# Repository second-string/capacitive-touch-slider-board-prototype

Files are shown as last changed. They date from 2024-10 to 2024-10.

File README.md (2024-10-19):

# capacitive-touch-slider-board-prototype

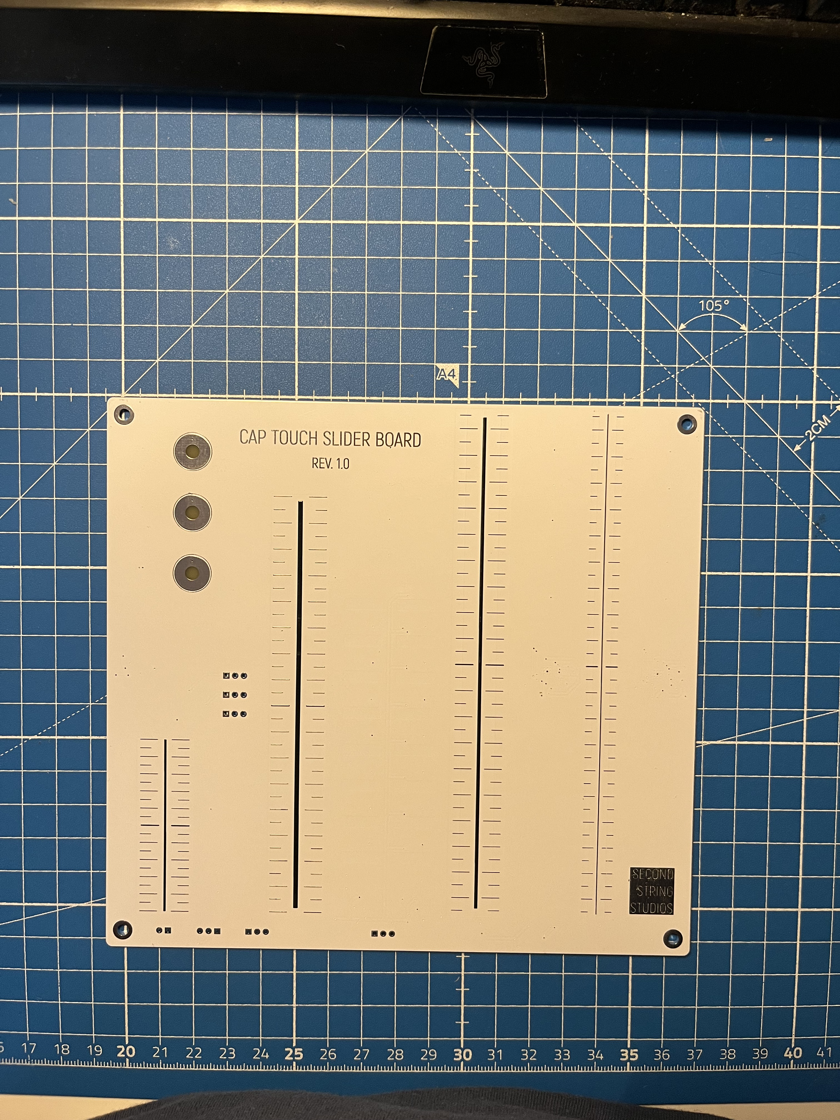
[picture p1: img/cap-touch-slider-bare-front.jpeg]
Version 1.0 of the capacitive touch slider test board front

Version 1.0 of the capacitive touch slider test board back

This repo contains a design for a prototype PCB for testing different capacitive touch slider designs. For more information on the different slider footprints, see [writeup](https://brian.team/engineering/capacitive-touch-protoype-pcbs/).

There is a schematic PDF and PCB layer prints PDF in the version 1.0 directory if you do not have KiCad. There are also Excel and interactive BOMs in the `bom/` subdirectory.

Reach out if you would like the KiCad slider schematic symbol and footprint files, they are saved in my global library and so not directly accessible from the project directory.

There is test firmware in `slider-board_rev_1_0/bringup_firmware/`. **NOTE:** This firmware is sloppy, terribly written, inefficient, and everything is hardcoded. It is only included as a reference, do not think that this will work for you out of the box.

Videos of example behavior are in the `img/` directory.

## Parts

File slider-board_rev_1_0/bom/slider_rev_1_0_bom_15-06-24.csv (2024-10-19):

Reference | Value | Footprint | Qty | DNP | Digikey | MPN | Purchase-URL
C1,C2,C4,C6,C7 | 0.1uF | Capacitor_SMD:C_0603_1608Metric | 5
C3,C5 | 4.7nF | Capacitor_SMD:C_0603_1608Metric | 2
D1,D2,D3,D4,D5,D6,D7,D8,D9,D10,D11,D12,D13,D14,D15,D16 | LED | LED_SMD:LED_SunLED_XZ_Reverse_Mount | 16
J2,J4,J5 | Conn_01x03_Pin | Connector_PinHeader_2.54mm:PinHeader_1x03_P2.54mm_Vertical | 3
J3 | Conn_01x02_Pin | Connector_PinHeader_2.54mm:PinHeader_1x02_P2.54mm_Vertical | 1
P1 | Slider_Spatial_3P_1L | Touch:Slider_SpatialInterpolation_3P_1L | 1
P2,P5,P6,P8,P9 | ~ | -- mixed values -- | 5
P7 | Slider_Resistive_3P_1L | Touch:Slider_ResistiveInterpolation_3P_1L | 1
Q1,Q2,Q3,Q4,Q5,Q6,Q7,Q8,Q9,Q10,Q11,Q12,Q13,Q14,Q15,Q16 | Q_NMOS_GSD | Package_TO_SOT_SMD:TSOT-23 | 16
R1,R17,R48 | 47k | Resistor_SMD:R_0603_1608Metric | 3
R4,R5,R6,R37,R38,R95,R96,R97 | 10k | Resistor_SMD:R_0603_1608Metric | 8
R7,R9,R14,R20,R25,R30,R33,R35,R36,R60,R61,R62,R63,R64,R65,R66,R67,R68 | 1k | Resistor_SMD:R_0603_1608Metric | 18
R8,R10,R32,R34,R39,R40,R58,R59 | 2k4 | Resistor_SMD:R_0603_1608Metric | 8
R11,R12,R13,R15,R16,R18,R19,R21,R22,R23,R24,R26,R27,R28,R29,R31,R41,R42,R43,R44,R45,R46,R47,R49,R50,R51,R52,R53,R54,R55,R56,R57 | 1k2 | Resistor_SMD:R_0603_1608Metric | 32
R69,R70,R71,R72,R73,R74,R75,R76,R77,R78,R79,R80,R81,R82,R83,R84 | 470R 1/2W | Resistor_SMD:R_0603_1608Metric | 16
R85,R86,R87,R92,R93,R94 | 2k | Resistor_SMD:R_0603_1608Metric | 6
R88,R89,R90,R91 | 1k5 | Resistor_SMD:R_0603_1608Metric | 4
TP1,TP2 | TestPoint | TestPoint:TestPoint_Pad_D3.0mm | 2
U1 | AT42QT2120 | Package_SO:TSSOP-20_4.4x6.5mm_P0.65mm | 1 |  | https://www.digikey.de/en/products/detail/microchip-technology/AT42QT2120-XUR/3678735 | AT42QT2120-XUR
U2,U3 | AT42QT2160-MMU | Package_DFN_QFN:VQFN-28-1EP_4x4mm_P0.45mm_EP2.4x2.4mm_ThermalVias | 2 |  |  | AT42QT2160-MMU | https://www.snapeda.com/api/url_track_click_mouser/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
U4,U5 | 74HCT595 | Package_DFN_QFN:DHVQFN-16-1EP_2.5x3.5mm_P0.5mm_EP1x2mm | 2

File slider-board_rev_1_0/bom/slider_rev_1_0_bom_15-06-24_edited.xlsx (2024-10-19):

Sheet: Sheet1
Reference | Value | Footprint | Qty | MPN | Digikey | LCSC
C1,C2,C4,C6,C7 | 0.1uF | Capacitor_SMD:C_0603_1608Metric | 5
C3,C5 | 4.7nF | Capacitor_SMD:C_0603_1608Metric | 2
D1,D2,D3,D4,D5,D6,D7,D8,D9,D10,D11,D12,D13,D14,D15,D16 | LED | LED_SMD:LED_SunLED_XZ_Reverse_Mount | 16 | XZMYK45WT-9 | https://www.digikey.de/en/products/detail/sunled/XZMYK45WT-9/6615715
J2,J4,J5 | Conn_01x03_Pin | Connector_PinHeader_2.54mm:PinHeader_1x03_P2.54mm_Vertical | 3
J3 | Conn_01x02_Pin | Connector_PinHeader_2.54mm:PinHeader_1x02_P2.54mm_Vertical | 1
Q1,Q2,Q3,Q4,Q5,Q6,Q7,Q8,Q9,Q10,Q11,Q12,Q13,Q14,Q15,Q16 | Q_NMOS_GSD | Package_TO_SOT_SMD:TSOT-23 | 16 | DMN3731U-7 | https://www.digikey.com/en/products/detail/diodes-incorporated/DMN3731U-7/10295271
R1,R17,R48 | 47k | Resistor_SMD:R_0603_1608Metric | 3
R4,R5,R6,R37,R38,R95,R96,R97 | 10k | Resistor_SMD:R_0603_1608Metric | 8
R7,R9,R14,R20,R25,R30,R33,R35,R36,R60,R61,R62,R63,R64,R65,R66,R67,R68 | 1k | Resistor_SMD:R_0603_1608Metric | 18
R8,R10,R32,R34,R39,R40,R58,R59 | 2k4 | Resistor_SMD:R_0603_1608Metric | 8 | RC0603FR-072K4L | https://www.digikey.de/en/products/detail/yageo/RC0603FR-072K4L/727023
R11,R12,R13,R15,R16,R18,R19,R21,R22,R23,R24,R26,R27,R28,R29,R31,R41,R42,R43,R44,R45,R46,R47,R49,R50,R51,R52,R53,R54,R55,R56,R57 | 1k2 | Resistor_SMD:R_0603_1608Metric | 32 | RMCF0603FT1K20 | https://www.digikey.de/en/products/detail/stackpole-electronics-inc/RMCF0603FT1K20/1761134
R69,R70,R71,R72,R73,R74,R75,R76,R77,R78,R79,R80,R81,R82,R83,R84 | 470R 1/2W | Resistor_SMD:R_0603_1608Metric | 16 | RCS0603470RJNEA | https://www.digikey.de/en/products/detail/vishay-dale/RCS0603470RJNEA/5866959
R85,R86,R87,R92,R93,R94 | 2k | Resistor_SMD:R_0603_1608Metric | 6 | RMCF0603FT2K00 | https://www.digikey.de/en/products/detail/stackpole-electronics-inc/RMCF0603FT2K00/1761334
R88,R89,R90,R91 | 1k5 | Resistor_SMD:R_0603_1608Metric | 4 | RMCF0603FT1K50 | https://www.digikey.de/en/products/detail/stackpole-electronics-inc/RMCF0603FT1K50/1761186
U1 | AT42QT2120 | Package_SO:TSSOP-20_4.4x6.5mm_P0.65mm | 1 | AT42QT2120-XUR | https://www.digikey.de/en/products/detail/microchip-technology/AT42QT2120-XUR/3678735
U2,U3 | AT42QT2160-MMU | Package_DFN_QFN:VQFN-28-1EP_4x4mm_P0.45mm_EP2.4x2.4mm_ThermalVias | 2 | AT42QT2160-MMU | https://www.digikey.de/en/products/detail/microchip-technology/AT42QT2160-MMUR/7354599
U4,U5 | 74HCT595 | Package_DFN_QFN:DHVQFN-16-1EP_2.5x3.5mm_P0.5mm_EP1x2mm | 2 | 74HCT595BQ,115 | https://www.digikey.de/en/products/detail/nexperia-usa-inc/74HCT595BQ-115/1023167

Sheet: Sheet2
XZMYK45WT-9 | 16
DMN3731U-7 | 16
RC0603FR-072K4L | 8
RMCF0603FT1K20 | 32
RCS0603470RJNEA | 16
RMCF0603FT2K00 | 6
RMCF0603FT1K50 | 4
AT42QT2120-XUR | 1
AT42QT2160-MMU | 2
74HCT595BQ,115 | 2

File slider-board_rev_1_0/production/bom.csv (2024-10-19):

Designator | Footprint | Quantity | Value | LCSC Part #
C1, C2, C4, C6, C7 | 0603 | 5 | 0.1uF
C3, C5 | 0603 | 2 | 4.7nF
D1, D10, D11, D12, D13, D14, D15, D16, D2, D3, D4, D5, D6, D7, D8, D9 | LED_SunLED_XZ_Reverse_Mount | 16 | LED
J2, J4, J5 | PinHeader_1x03_P2.54mm_Vertical | 3 | Conn_01x03_Pin
J3 | PinHeader_1x02_P2.54mm_Vertical | 1 | Conn_01x02_Pin
P1 | Slider_SpatialInterpolation_3P_1L | 1 | Slider_Spatial_3P_1L
P2, P5, P6 | Cap_Touch_Ring_Small | 3 | ~
P7 | Slider_ResistiveInterpolation_3P_1L | 1 | Slider_Resistive_3P_1L
P8 | Slider_ResistiveInterpolation_7P_2L | 1 | ~
P9 | Slider_ResistiveInterpolation_Thin_7P_2L | 1 | ~
Q1, Q10, Q11, Q12, Q13, Q14, Q15, Q16, Q2, Q3, Q4, Q5, Q6, Q7, Q8, Q9 | TSOT-23 | 16 | Q_NMOS_GSD
R1, R17, R48 | 0603 | 3 | 47k
R10, R32, R34, R39, R40, R58, R59, R8 | 0603 | 8 | 2k4
R11, R12, R13, R15, R16, R18, R19, R21, R22, R23, R24, R26, R27, R28, R29, R31, R41, R42, R43, R44, R45, R46, R47, R49, R50, R51, R52, R53, R54, R55, R56, R57 | 0603 | 32 | 1k2
R14, R20, R25, R30, R33, R35, R36, R60, R61, R62, R63, R64, R65, R66, R67, R68, R7, R9 | 0603 | 18 | 1k
R37, R38, R4, R5, R6, R95, R96, R97 | 0603 | 8 | 10k
R69, R70, R71, R72, R73, R74, R75, R76, R77, R78, R79, R80, R81, R82, R83, R84 | 0603 | 16 | 470R 1/2W
R85, R86, R87, R92, R93, R94 | 0603 | 6 | 2k
R88, R89, R90, R91 | 0603 | 4 | 1k5
TP1, TP2 | TestPoint_Pad_D3.0mm | 2 | TestPoint
U1 | TSSOP-20_4.4x6.5mm_P0.65mm | 1 | AT42QT2120 | AT42QT2120-XUR
U2, U3 | VQFN-28-1EP_4x4mm_P0.45mm_EP2.4x2.4mm_ThermalVias | 2 | AT42QT2160-MMU | AT42QT2160-MMU
U4, U5 | DHVQFN-16-1EP_2.5x3.5mm_P0.5mm_EP1x2mm | 2 | 74HCT595

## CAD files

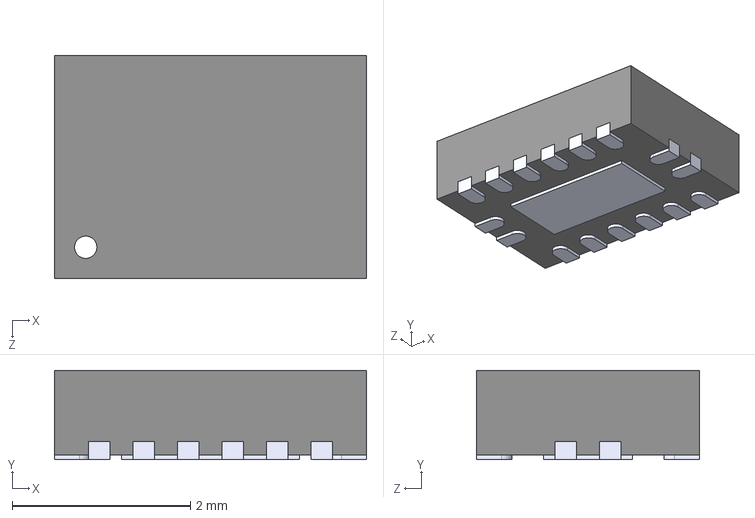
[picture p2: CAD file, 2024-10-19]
slider-board_rev_1_0/symbols_and_footprints/74HCT595BQ/74HCT595BQ-Q100,11.STEP
3.50 x 1.00 x 2.50 mm

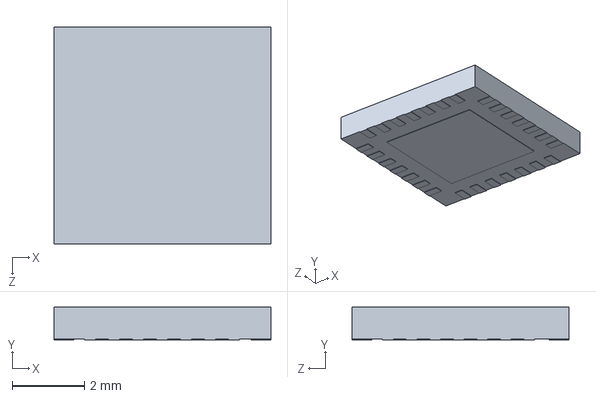
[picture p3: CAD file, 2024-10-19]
slider-board_rev_1_0/symbols_and_footprints/AT42QT2160-MMU/AT42QT2160-MMU.step
6.00 x 0.9 x 6.00 mm

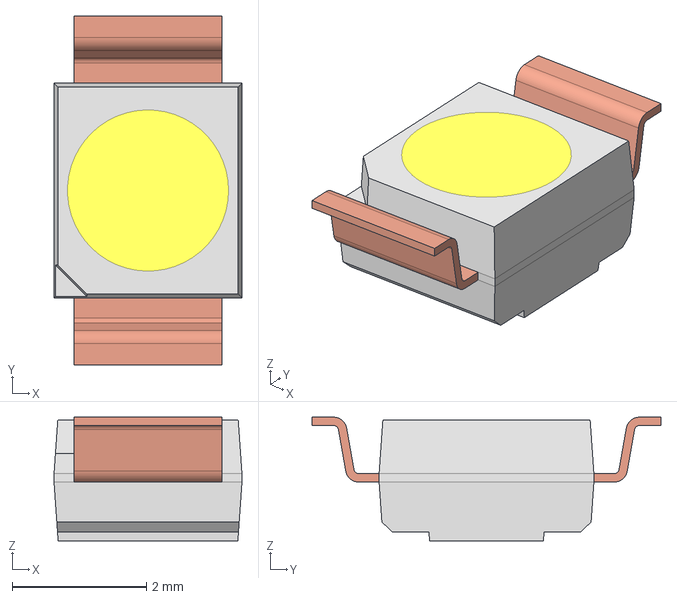
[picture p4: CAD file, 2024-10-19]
slider-board_rev_1_0/symbols_and_footprints/XZxx45S/80472LED_SMD_PLCC-2_reverse_gullwing.stp
2.80 x 5.20 x 1.84 mm

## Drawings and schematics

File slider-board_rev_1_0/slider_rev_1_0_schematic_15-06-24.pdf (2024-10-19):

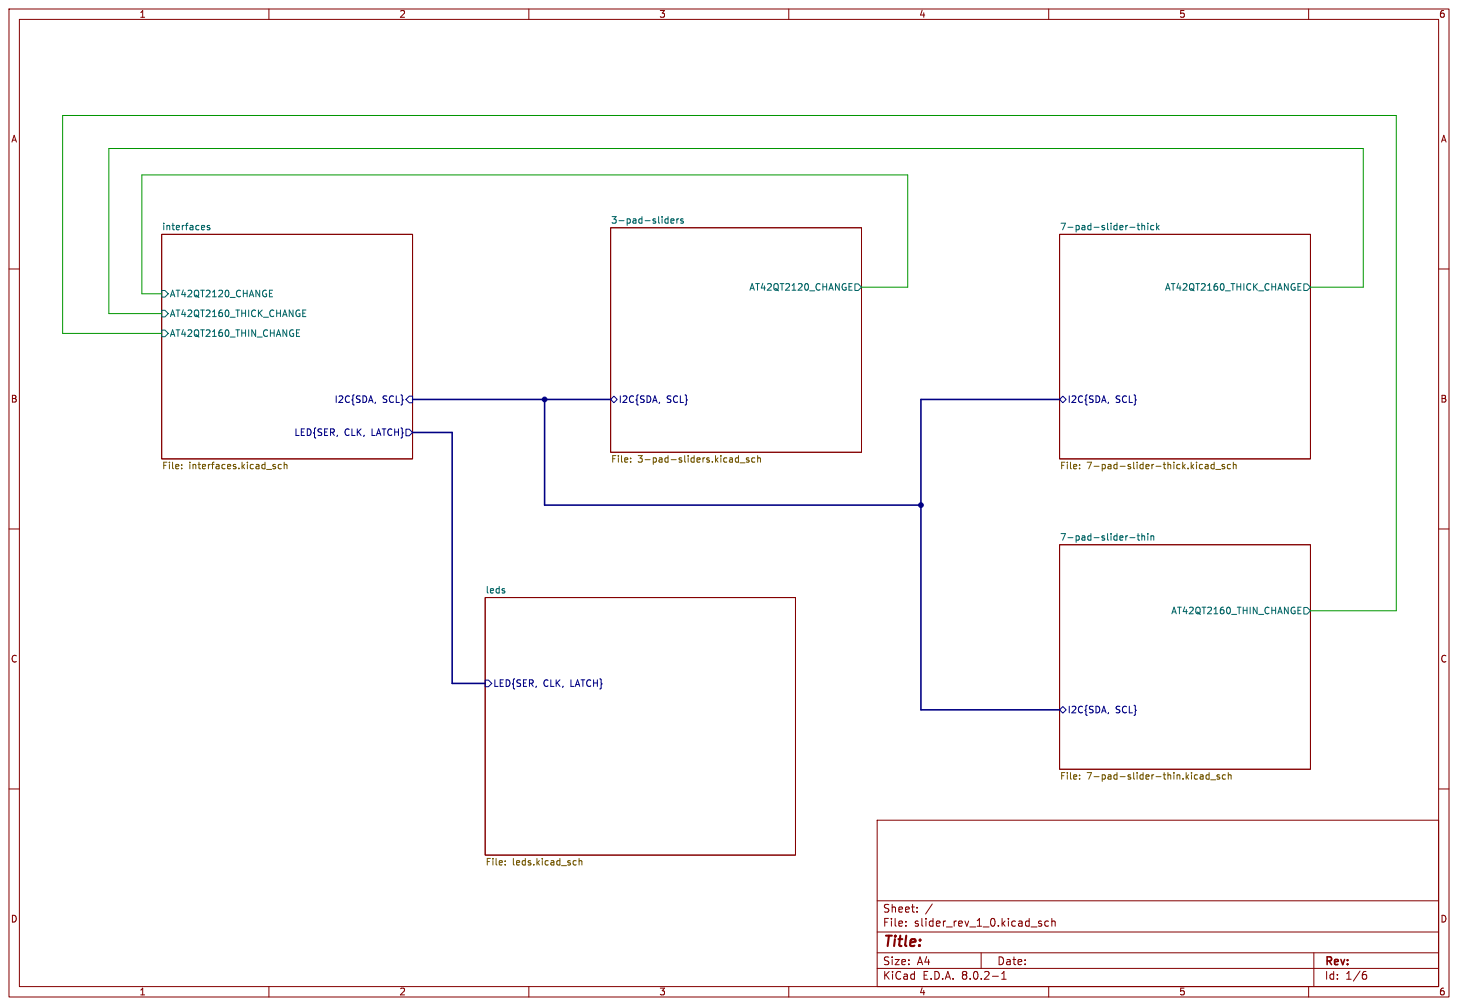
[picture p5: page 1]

3-pad-sliders File: 3-pad-sliders.kicad_sch

7-pad-slider-thick File: 7-pad-slider-thick.kicad_sch

LED{SER, CLK, LATCH}
leds File: leds.kicad_sch

7-pad-slider-thin File: 7-pad-slider-thin.kicad_sch

Id: 1/6 Title: File: slider_rev_1_0.kicad_sch Sheet: /

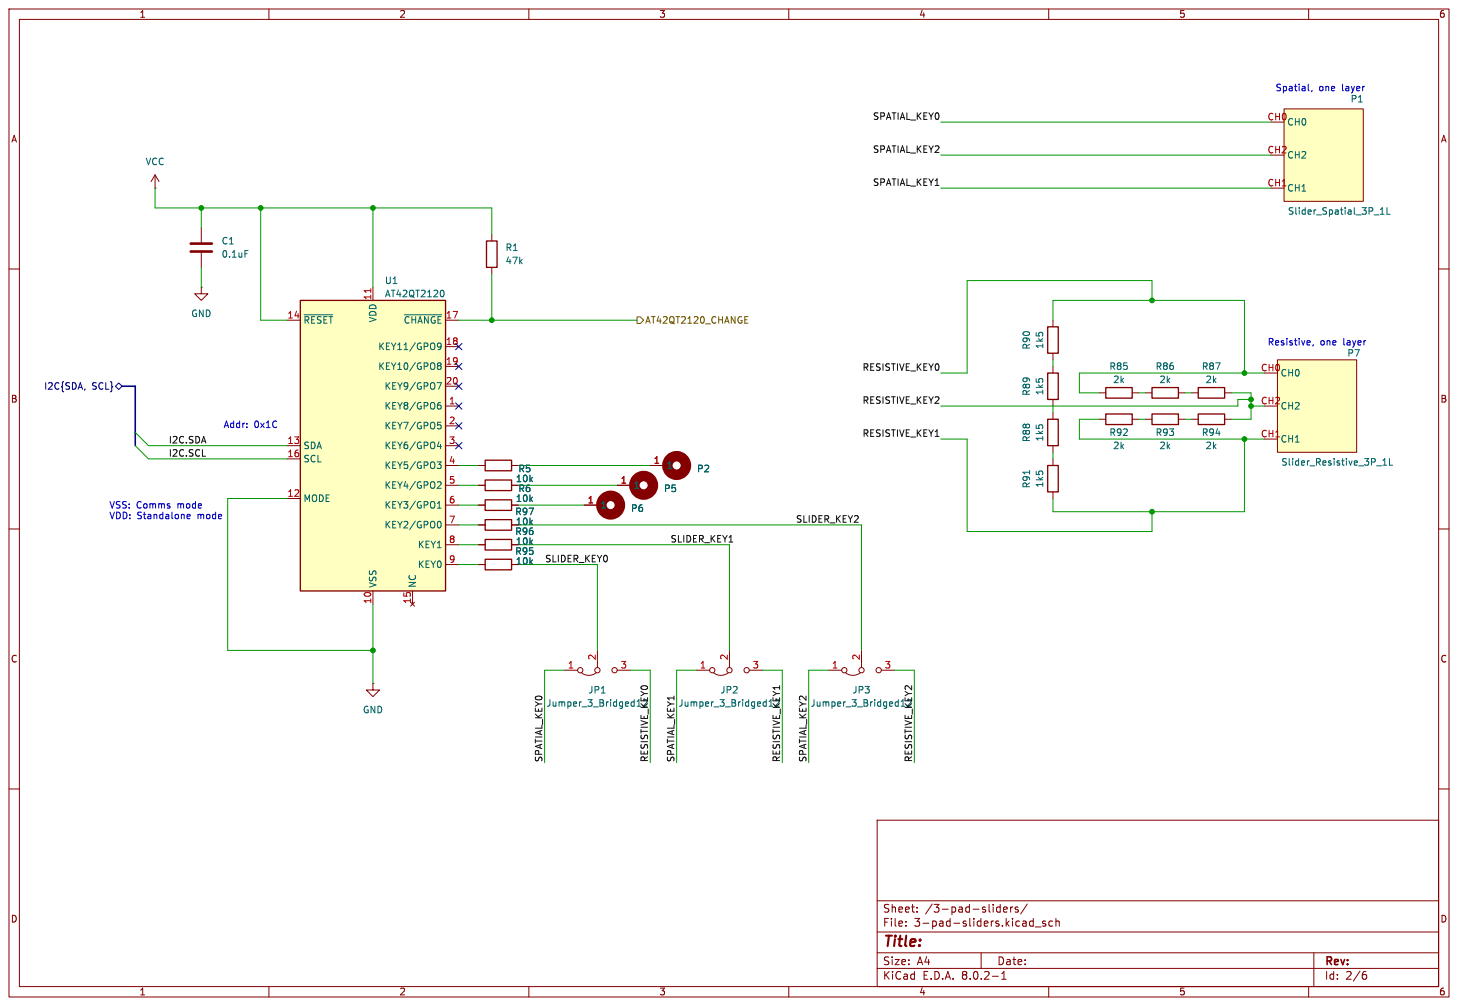
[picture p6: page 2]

Id: 2/6 Title: File: 3-pad-sliders.kicad_sch Sheet: /3-pad-sliders/

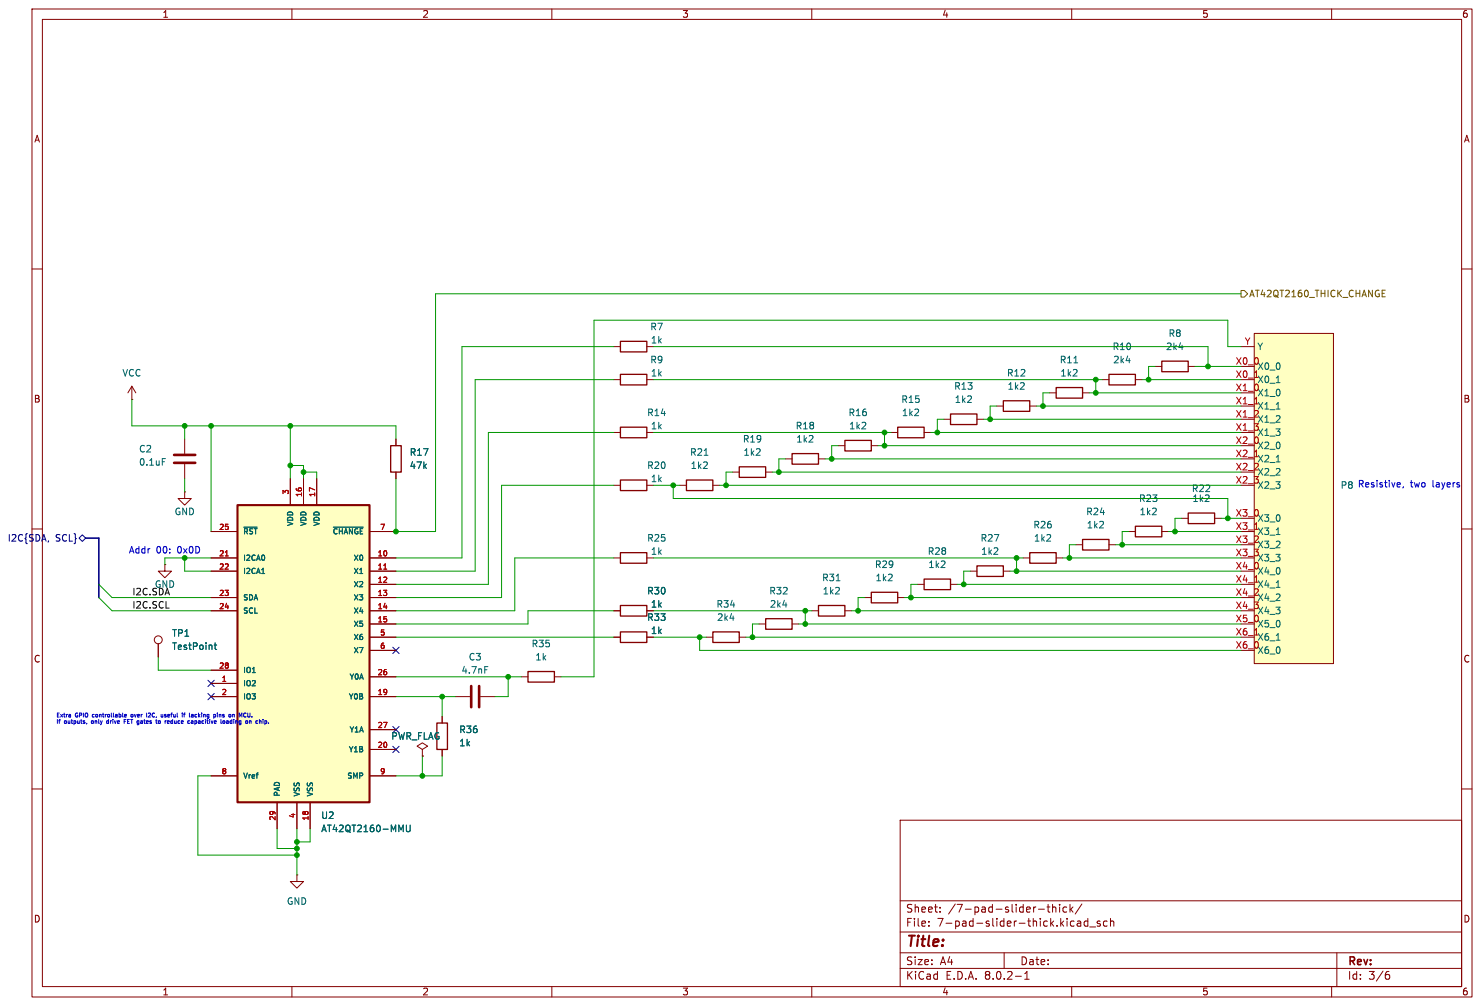
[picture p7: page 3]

4 X6 5 X7 6 ~{CHANGE} 7 Vref 8 SMP 9 U2AT42QT2160-MMU GND

Id: 3/6 Title: File: 7-pad-slider-thick.kicad_sch Sheet: /7-pad-slider-thick/

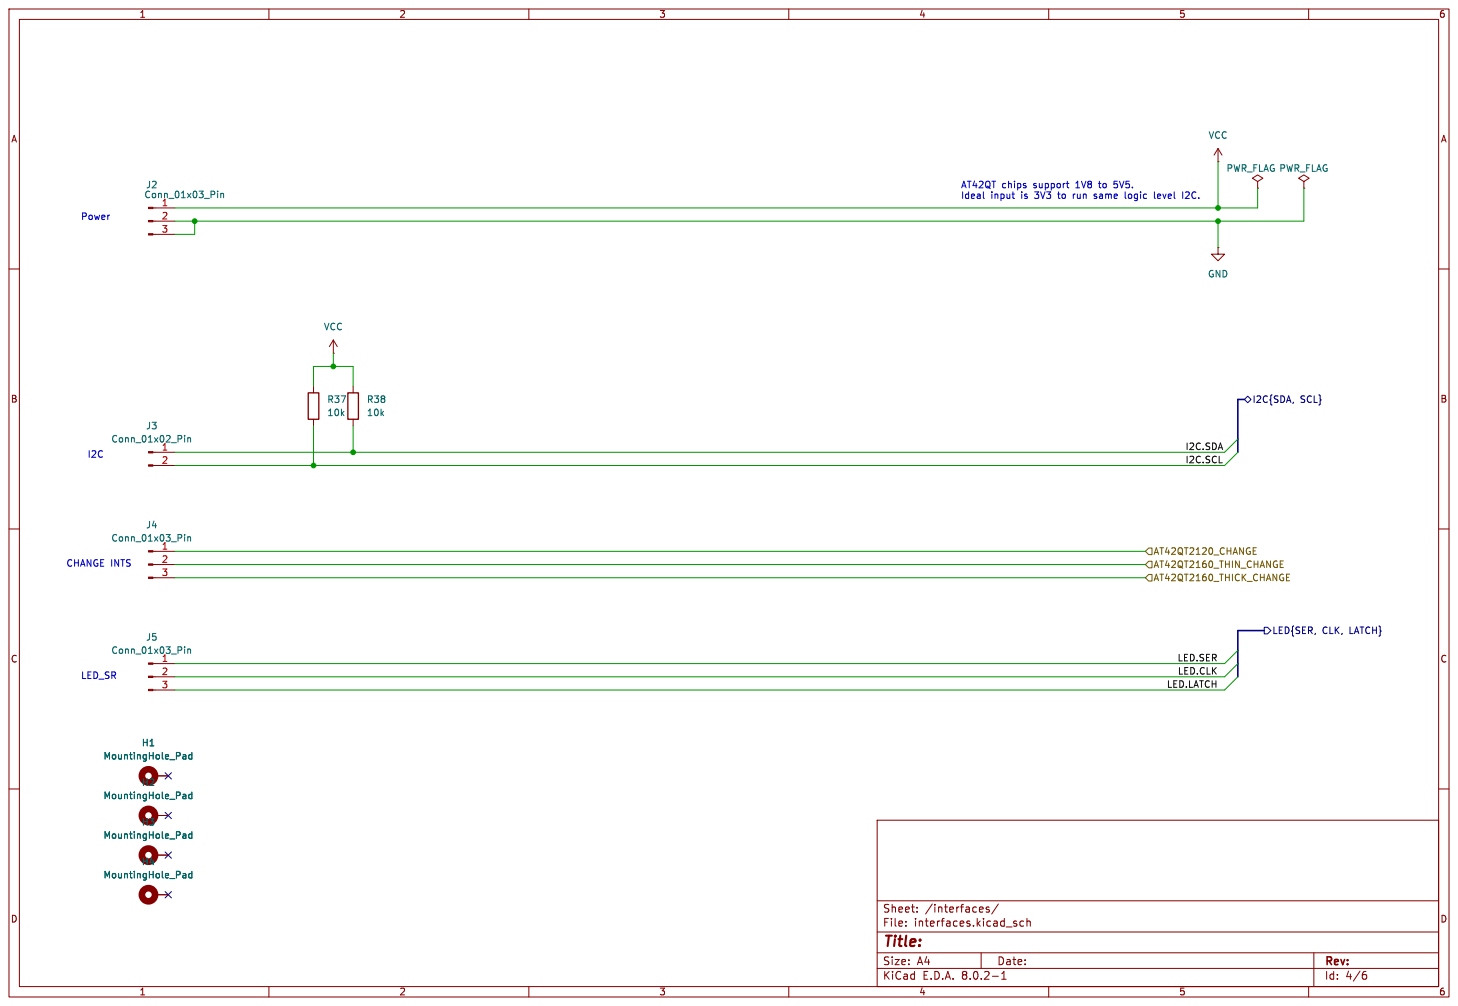
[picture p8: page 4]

Ideal input is 3V3 to run same logic level I2C. H1 MountingHole_Pad H4 MountingHole_Pad H2 MountingHole_Pad H3 MountingHole_Pad

LED{SER, CLK, LATCH}

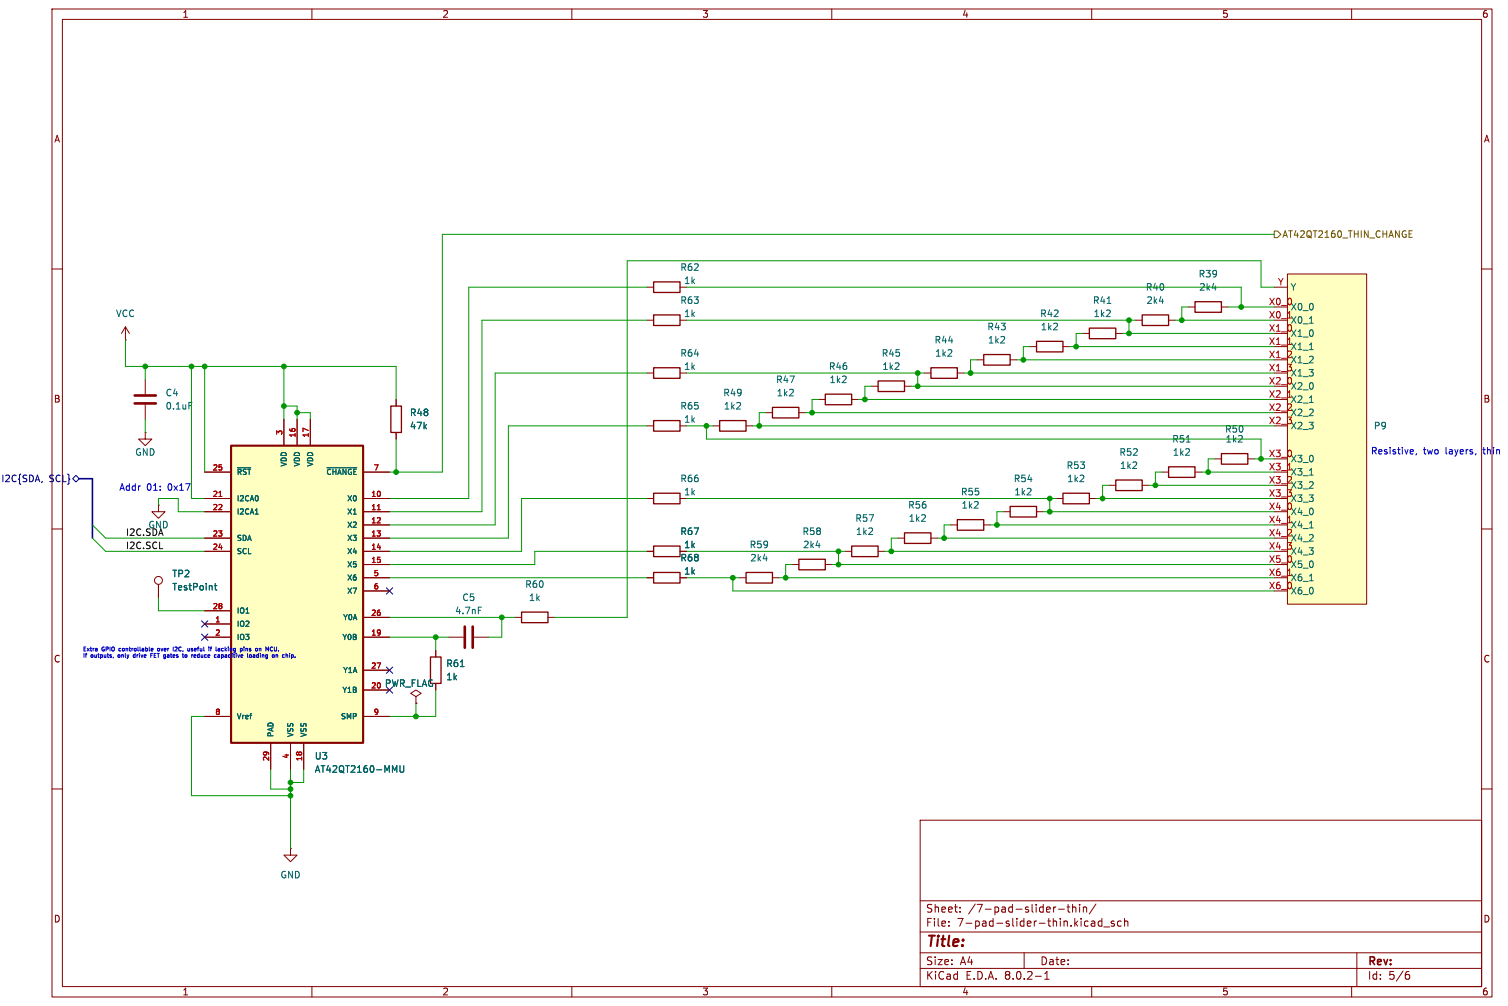
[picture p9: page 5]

4 X6 5 X7 6 ~{CHANGE} 7 Vref 8 SMP 9 TP2 TestPoint R48

4 X6 5 X7 6 ~{CHANGE} 7 Vref 8 SMP 9 U3AT42QT2160-MMU

Id: 5/6 Title: File: 7-pad-slider-thin.kicad_sch Sheet: /7-pad-slider-thin/

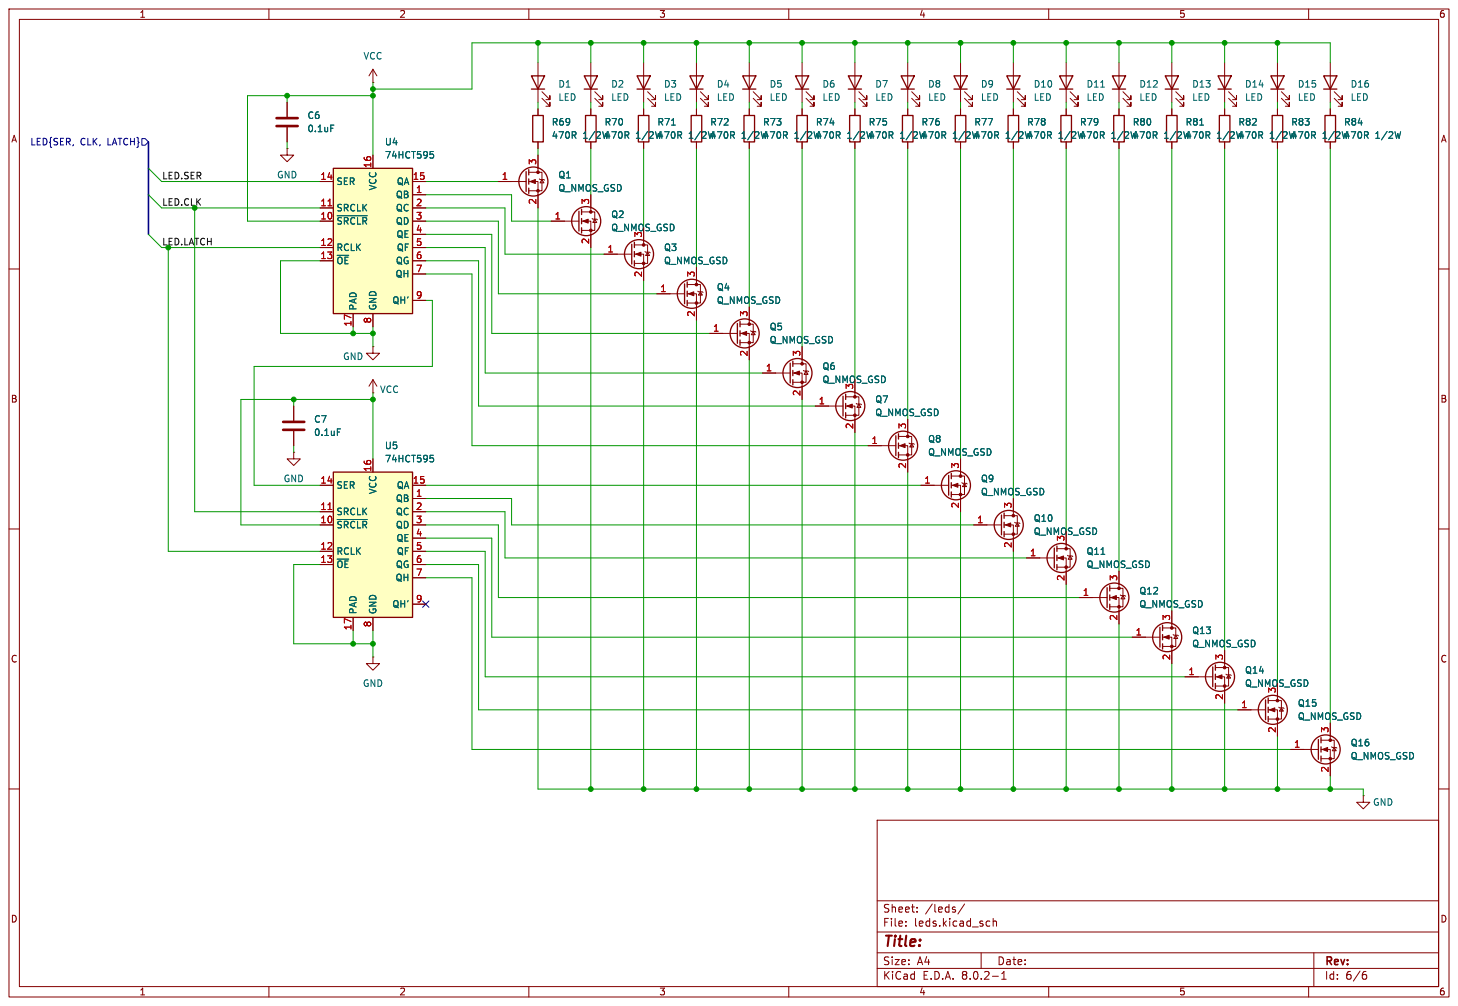
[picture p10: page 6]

Id: 6/6 Title: File: leds.kicad_sch Sheet: /leds/

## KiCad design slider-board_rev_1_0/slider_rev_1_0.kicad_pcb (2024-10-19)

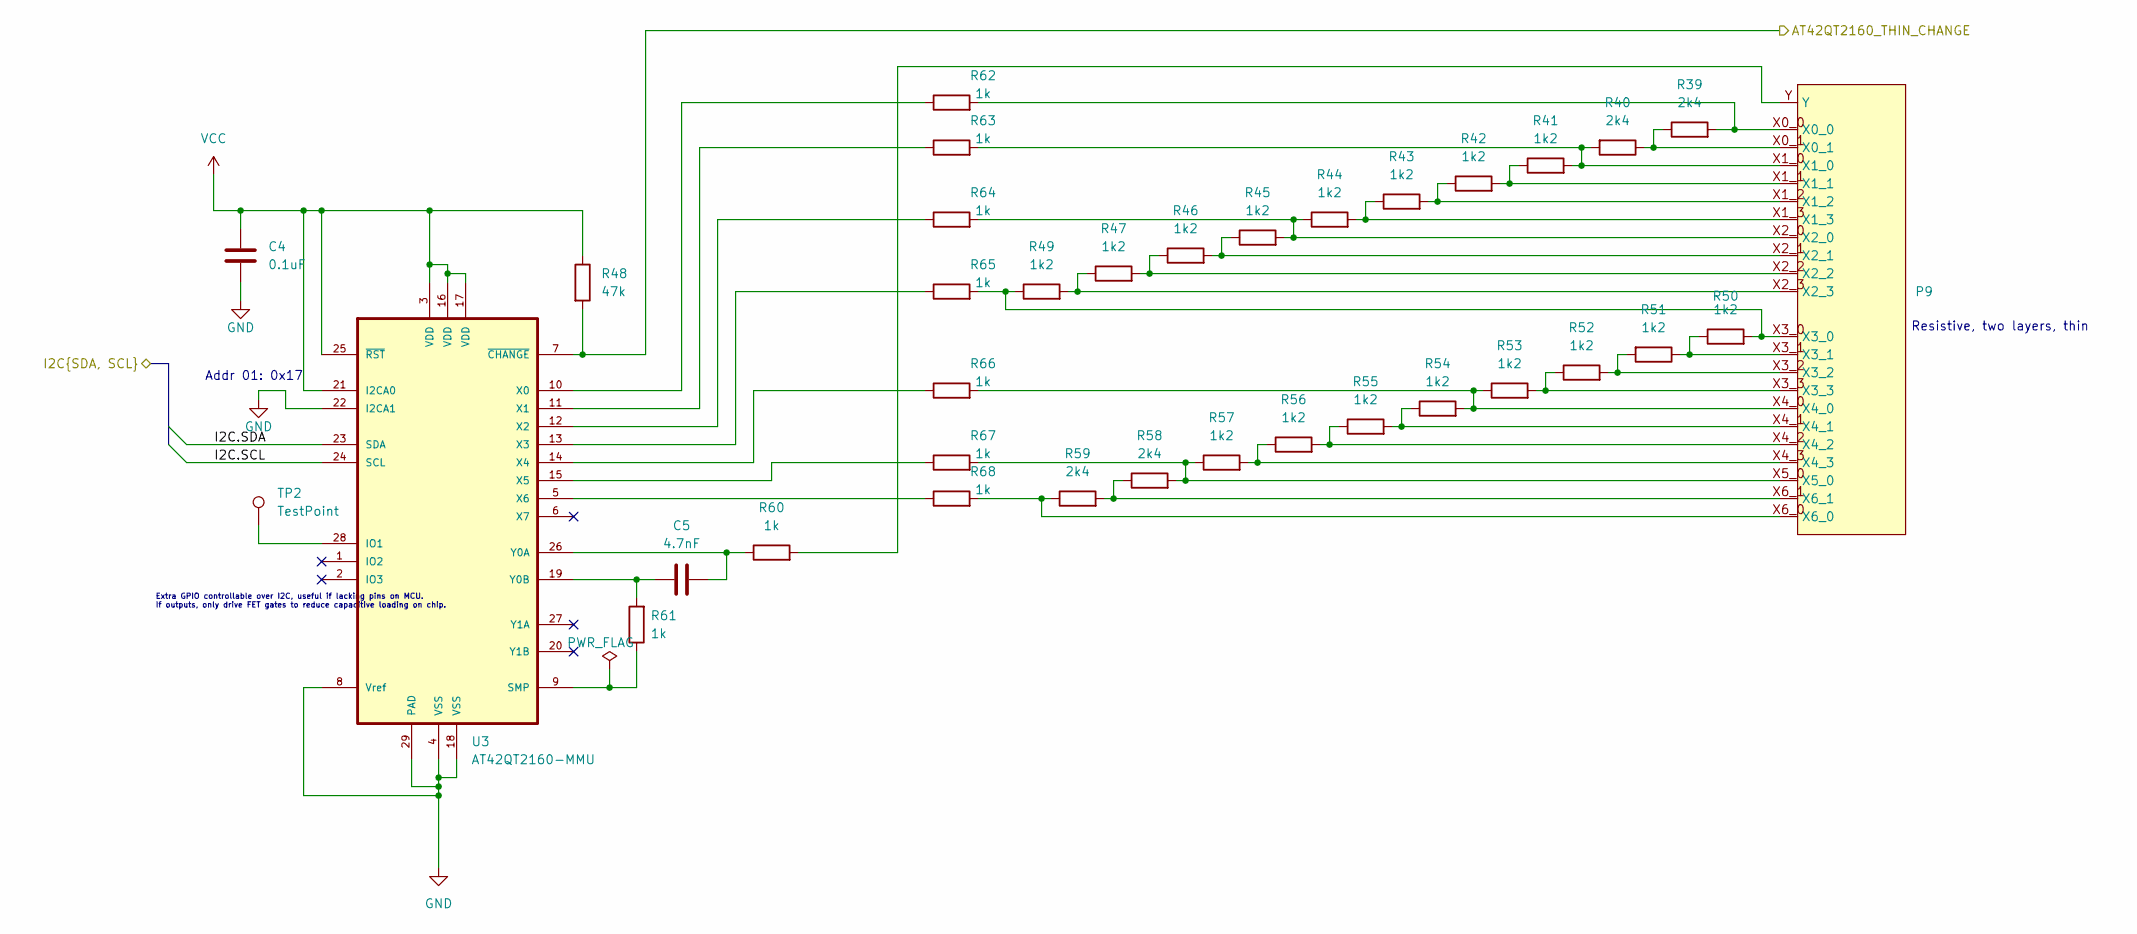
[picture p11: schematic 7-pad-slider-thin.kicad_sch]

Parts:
C4: 0.1uF; C_0603_1608Metric
C5: 4.7nF; C_0603_1608Metric
P9: Slider_ResistiveInterpolation_Thin_7P_2L
R39, R40, R58, R59: 2k4; R_0603_1608Metric
R41, R42, R43, R44, R45, R46, R47, R49, R50, R51, R52, R53, R54, R55, R56, R57: 1k2; R_0603_1608Metric
R48: 47k; R_0603_1608Metric
R60, R61, R62, R63, R64, R65, R66, R67, R68: 1k; R_0603_1608Metric
TP2: TestPoint; TestPoint_Pad_D3.0mm
U3: AT42QT2160-MMU; VQFN-28-1EP_4x4mm_P0.45mm_EP2.4x2.4mm_ThermalVias; MPN AT42QT2160-MMU

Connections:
/3-pad-sliders/I2C.SCL: U3.24 (SCL); also elsewhere on the board
/3-pad-sliders/I2C.SDA: U3.23 (SDA); also elsewhere on the board
/7-pad-slider-thin/AT42QT2160_THIN_CHANGE: R48.2, U3.7 (~CHANGE); also elsewhere on the board
GND: C4.2, U3.4 (VSS), U3.8 (Vref), U3.18 (VSS), U3.22 (I2CA1), U3.29 (PAD); also elsewhere on the board
unnamed: P9.X0_0, R39.2, R62.2
unnamed: P9.X0_1, R39.1, R40.1
unnamed: P9.X1_0, R40.2, R41.2, R63.2
unnamed: P9.X1_1, R41.1, R42.2
unnamed: P9.X1_2, R42.1, R43.2
unnamed: P9.X1_3, R43.1, R44.2
unnamed: P9.X2_0, R44.1, R45.2, R64.2
unnamed: P9.X2_1, R45.1, R46.2
unnamed: P9.X2_2, R46.1, R47.2
unnamed: P9.X2_3, R47.1, R49.2
unnamed: P9.X3_0, R49.1, R50.2, R65.2
unnamed: P9.X3_1, R50.1, R51.1
unnamed: P9.X3_2, R51.2, R52.2
unnamed: P9.X3_3, R52.1, R53.2
unnamed: P9.X4_0, R53.1, R54.2, R66.2
unnamed: P9.X4_1, R54.1, R55.2
unnamed: P9.X4_2, R55.1, R56.2
unnamed: P9.X4_3, R56.1, R57.2
unnamed: P9.X5_0, R57.1, R58.2, R67.2
unnamed: P9.X6_0, R59.1, R68.2
unnamed: P9.X6_1, R58.1, R59.2
unnamed: P9.Y, R60.2
unnamed: TP2.1, U3.28 (IO1)
unnamed: R61.1, U3.9 (SMP)
unnamed: R62.1, U3.10 (X0)
unnamed: R63.1, U3.11 (X1)
unnamed: R64.1, U3.12 (X2)
unnamed: R65.1, U3.13 (X3)
unnamed: R66.1, U3.14 (X4)
unnamed: R67.1, U3.15 (X5)
unnamed: R68.1, U3.5 (X6)
unnamed: C5.2, R60.1, U3.26 (Y0A)
unnamed: C5.1, R61.2, U3.19 (Y0B)
VCC: C4.1, R48.1, U3.3 (VDD), U3.16 (VDD), U3.17 (VDD), U3.21 (I2CA0), U3.25 (~RST); also elsewhere on the board

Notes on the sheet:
Resistive, two layers, thin
Extra GPIO controllable over I2C, useful if lacking pins on MCU. If outputs, only drive FET gates to reduce capacitive loading on chip.
Addr 01: 0x17

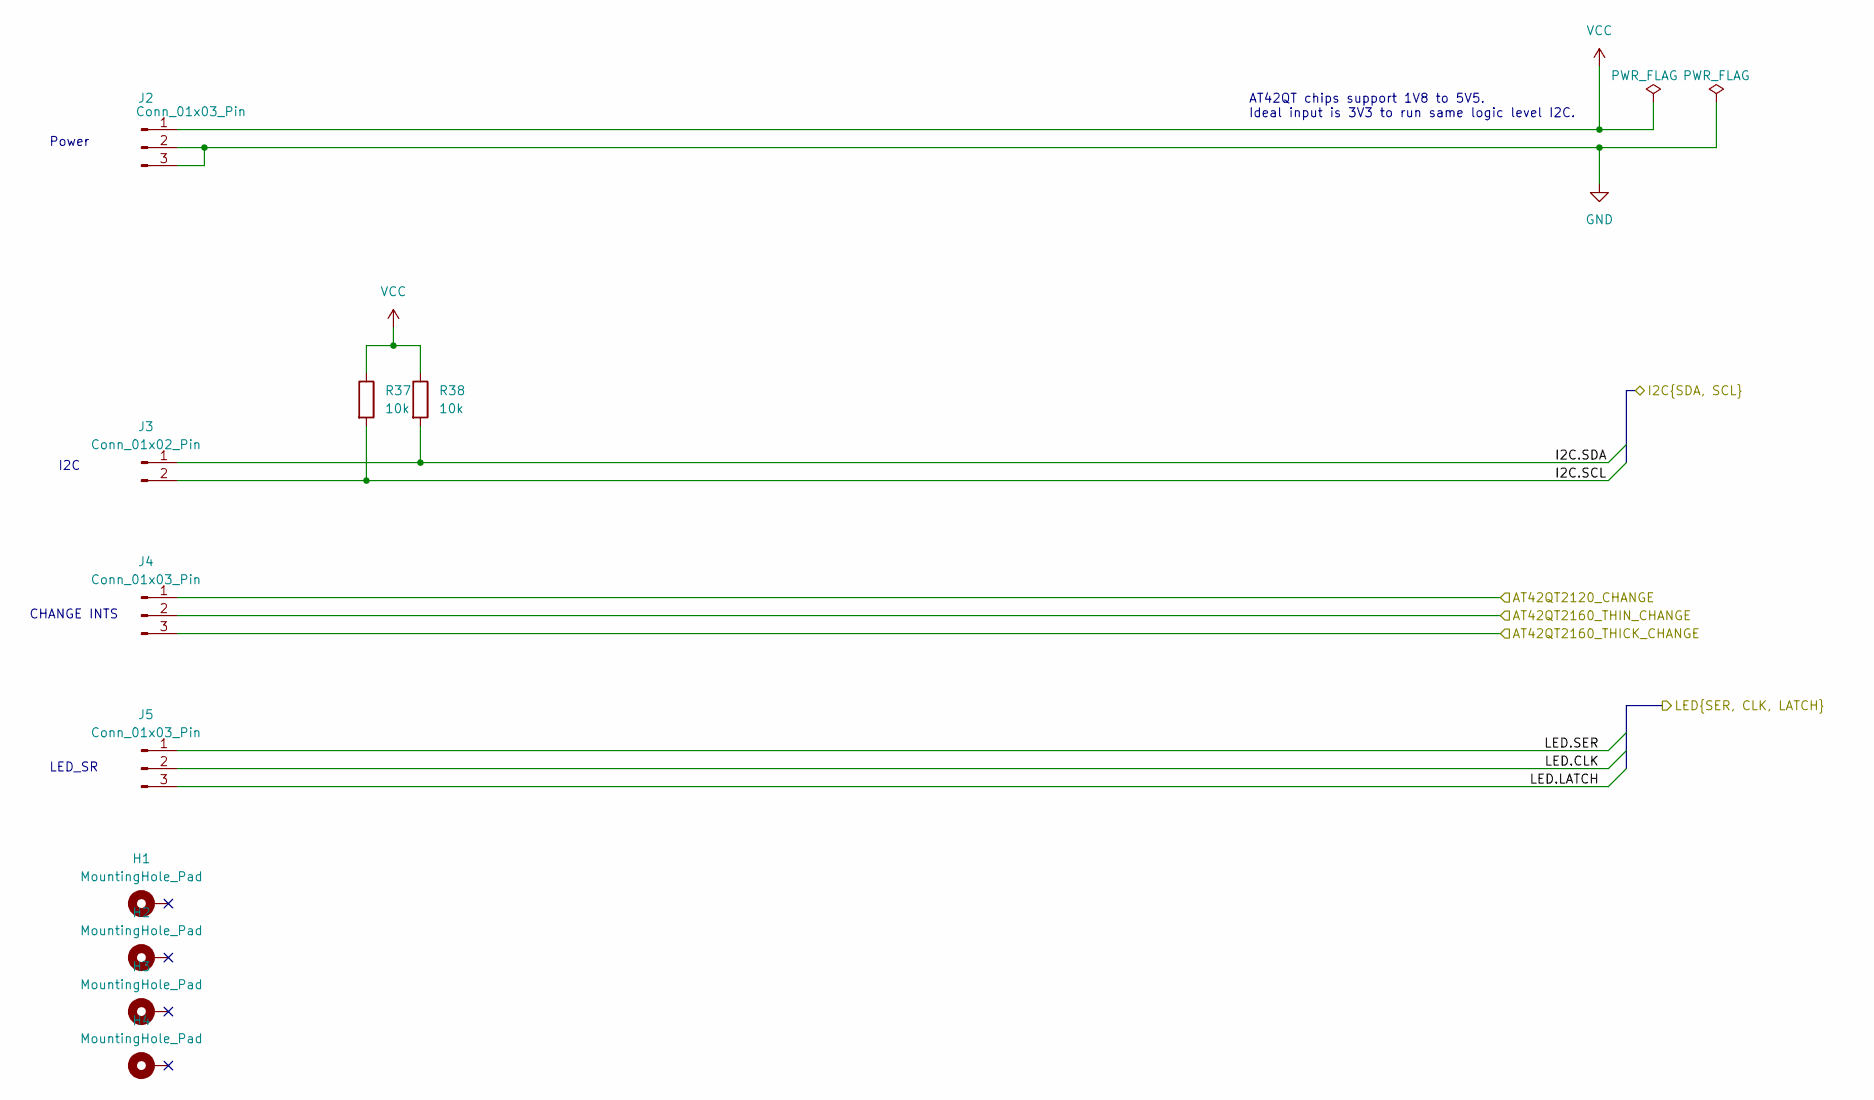
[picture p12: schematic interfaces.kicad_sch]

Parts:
H1, H2, H3, H4: MountingHole_Pad; MountingHole_3.2mm_M3_DIN965_Pad
J2, J4, J5: Conn_01x03_Pin; PinHeader_1x03_P2.54mm_Vertical
J3: Conn_01x02_Pin; PinHeader_1x02_P2.54mm_Vertical
R37, R38: 10k; R_0603_1608Metric

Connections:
/3-pad-sliders/AT42QT2120_CHANGE: J4.1; also elsewhere on the board
/3-pad-sliders/I2C.SCL: J3.2, R37.2; also elsewhere on the board
/3-pad-sliders/I2C.SDA: J3.1, R38.2; also elsewhere on the board
/7-pad-slider-thick/AT42QT2160_THICK_CHANGE: J4.3; also elsewhere on the board
/7-pad-slider-thin/AT42QT2160_THIN_CHANGE: J4.2; also elsewhere on the board
/interfaces/LED.CLK: J5.2; also elsewhere on the board
/interfaces/LED.LATCH: J5.3; also elsewhere on the board
/interfaces/LED.SER: J5.1; also elsewhere on the board
GND: J2.2, J2.3; also elsewhere on the board
VCC: J2.1, R37.1, R38.1; also elsewhere on the board

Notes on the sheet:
LED_SR
CHANGE INTS
AT42QT chips support 1V8 to 5V5. Ideal input is 3V3 to run same logic level I2C.
Power
I2C

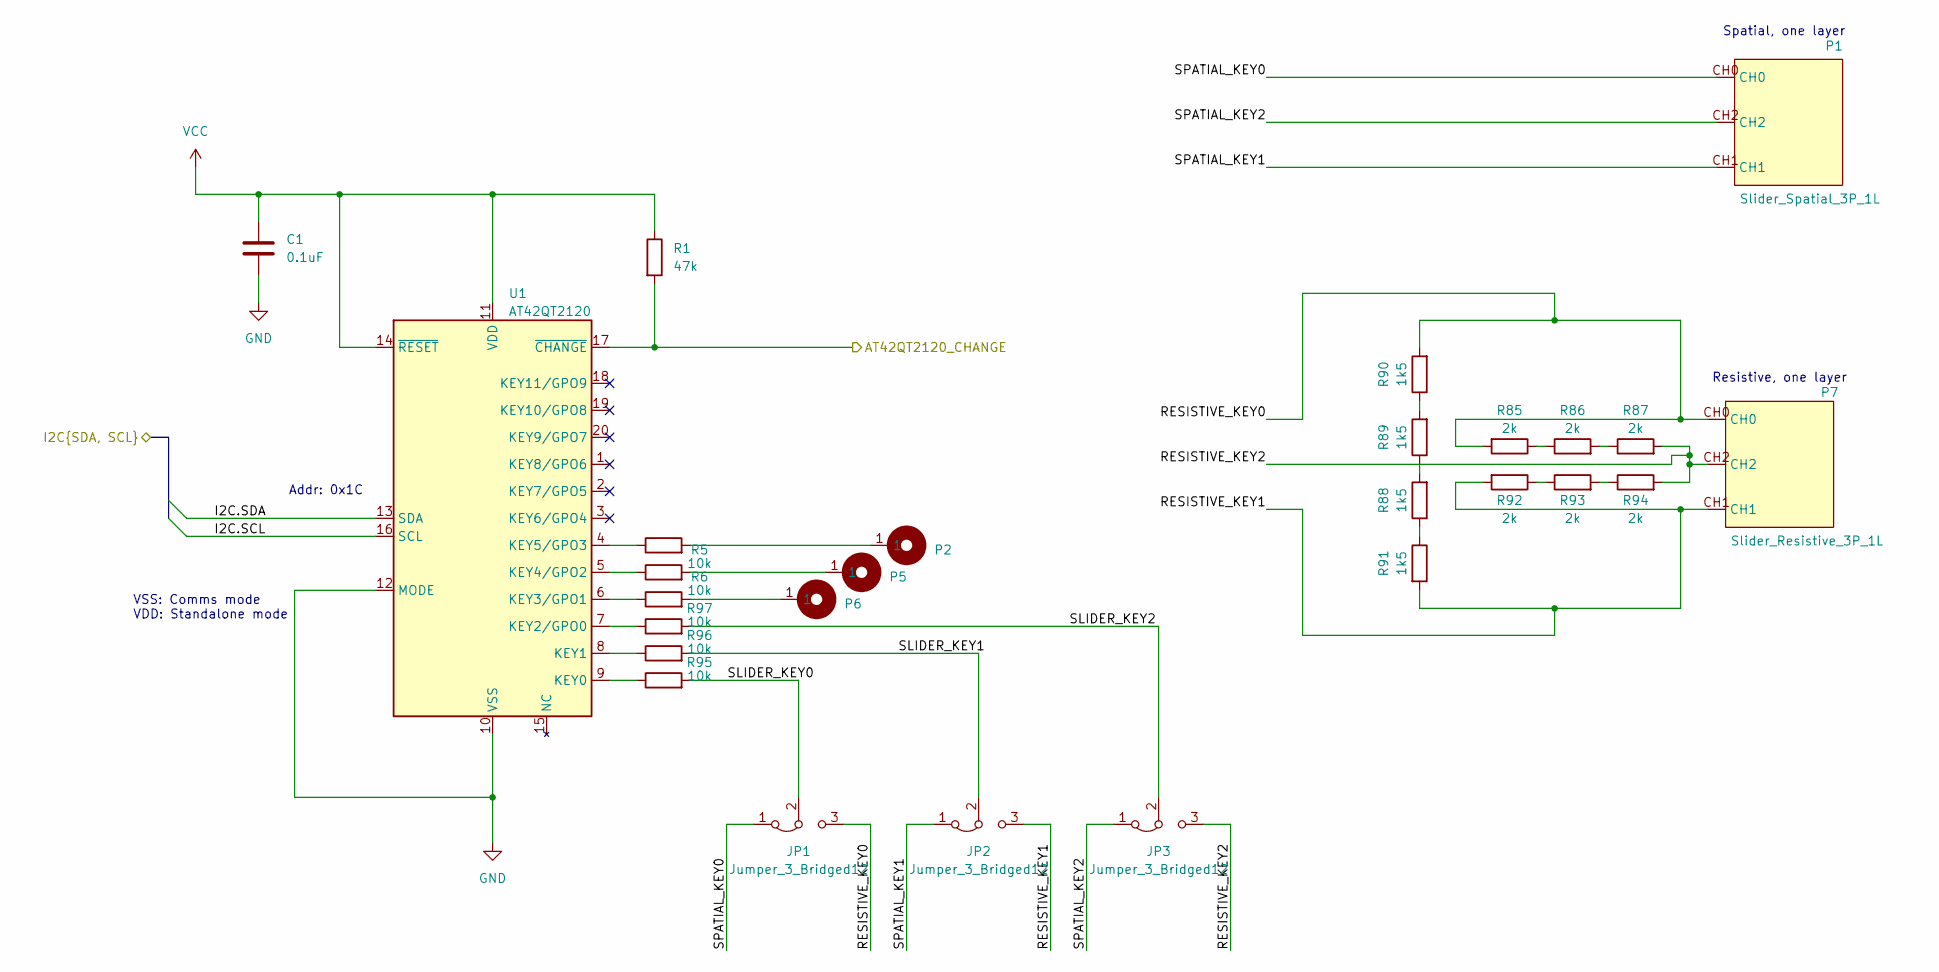
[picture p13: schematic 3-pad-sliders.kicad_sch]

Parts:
C1: 0.1uF; C_0603_1608Metric
JP1, JP2, JP3: Jumper_3_Bridged12; PinHeader_1x03_P2.54mm_Vertical
P1: Slider_Spatial_3P_1L; Slider_SpatialInterpolation_3P_1L
P2, P5, P6: Cap_Touch_Ring_Small
P7: Slider_Resistive_3P_1L; Slider_ResistiveInterpolation_3P_1L
R1: 47k; R_0603_1608Metric
R4, R5, R6, R95, R96, R97: 10k; R_0603_1608Metric
R85, R86, R87, R92, R93, R94: 2k; R_0603_1608Metric
R88, R89, R90, R91: 1k5; R_0603_1608Metric
U1: AT42QT2120; TSSOP-20_4.4x6.5mm_P0.65mm; MPN AT42QT2120-XUR

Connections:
/3-pad-sliders/AT42QT2120_CHANGE: R1.2, U1.17 (~CHANGE); also elsewhere on the board
/3-pad-sliders/I2C.SCL: U1.16 (SCL); also elsewhere on the board
/3-pad-sliders/I2C.SDA: U1.13 (SDA); also elsewhere on the board
/3-pad-sliders/RESISTIVE_KEY0: JP1.3 (B), P7.CH0, R85.2, R90.2
/3-pad-sliders/RESISTIVE_KEY1: JP2.3 (B), P7.CH1, R91.2, R92.2
/3-pad-sliders/RESISTIVE_KEY2: JP3.3 (B), P7.CH2, R87.2, R94.2
/3-pad-sliders/SLIDER_KEY0: JP1.2 (C), R95.2
/3-pad-sliders/SLIDER_KEY1: JP2.2 (C), R96.2
/3-pad-sliders/SLIDER_KEY2: JP3.2 (C), R97.2
/3-pad-sliders/SPATIAL_KEY0: JP1.1 (A), P1.CH0
/3-pad-sliders/SPATIAL_KEY1: JP2.1 (A), P1.CH1
/3-pad-sliders/SPATIAL_KEY2: JP3.1 (A), P1.CH2
GND: C1.2, U1.10 (VSS), U1.12 (MODE); also elsewhere on the board
unnamed: P2.1, R4.2
unnamed: P5.1, R5.2
unnamed: P6.1, R6.2
unnamed: R85.1, R86.1
unnamed: R86.2, R87.1
unnamed: R88.1, R91.1
unnamed: R88.2, R89.1
unnamed: R89.2, R90.1
unnamed: R92.1, R93.1
unnamed: R93.2, R94.1
unnamed: R95.1, U1.9 (KEY0)
unnamed: R96.1, U1.8 (KEY1)
unnamed: R97.1, U1.7 (KEY2/GPO0)
unnamed: R6.1, U1.6 (KEY3/GPO1)
unnamed: R5.1, U1.5 (KEY4/GPO2)
unnamed: R4.1, U1.4 (KEY5/GPO3)
VCC: C1.1, R1.1, U1.11 (VDD), U1.14 (~RESET); also elsewhere on the board

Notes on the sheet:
Resistive, one layer
VSS: Comms mode VDD: Standalone mode
Spatial, one layer
Addr: 0x1C

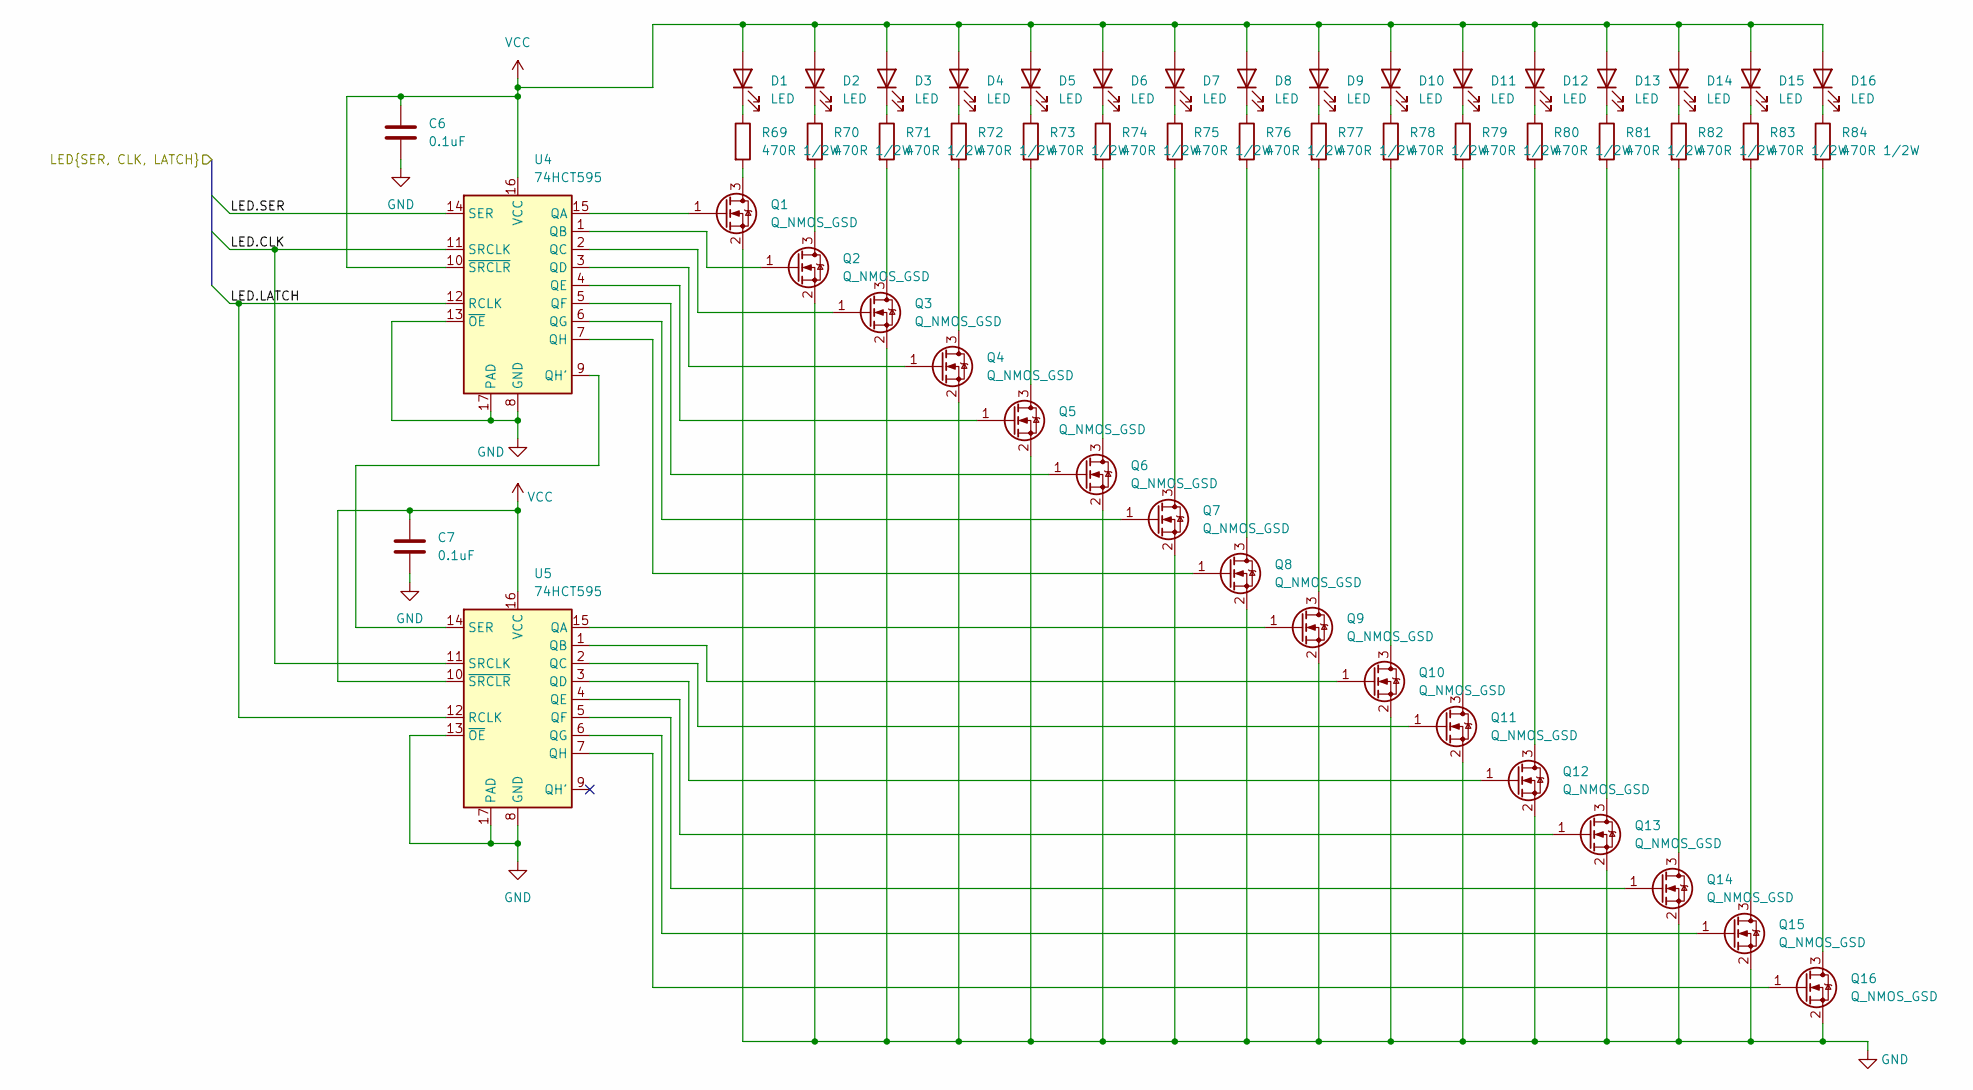
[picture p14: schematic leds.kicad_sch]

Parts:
C6, C7: 0.1uF; C_0603_1608Metric
D1, D2, D3, D4, D5, D6, D7, D8, D9, D10, D11, D12, D13, D14, D15, D16: LED; LED_SunLED_XZ_Reverse_Mount
Q1, Q2, Q3, Q4, Q5, Q6, Q7, Q8, Q9, Q10, Q11, Q12, Q13, Q14, Q15, Q16: Q_NMOS_GSD; TSOT-23
R69, R70, R71, R72, R73, R74, R75, R76, R77, R78, R79, R80, R81, R82, R83, R84: 470R 1/2W; R_0603_1608Metric
U4, U5: 74HCT595; DHVQFN-16-1EP_2.5x3.5mm_P0.5mm_EP1x2mm

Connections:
/interfaces/LED.CLK: U4.11 (SRCLK), U5.11 (SRCLK); also elsewhere on the board
/interfaces/LED.LATCH: U4.12 (RCLK), U5.12 (RCLK); also elsewhere on the board
/interfaces/LED.SER: U4.14 (SER); also elsewhere on the board
GND: C6.2, C7.2, Q1.2 (S), Q2.2 (S), Q3.2 (S), Q4.2 (S), Q5.2 (S), Q6.2 (S), Q7.2 (S), Q8.2 (S), Q9.2 (S), Q10.2 (S), Q11.2 (S), Q12.2 (S), Q13.2 (S), Q14.2 (S), Q15.2 (S), Q16.2 (S), U4.8 (GND), U4.13 (~OE), U4.17 (PAD), U5.8 (GND), U5.13 (~OE), U5.17 (PAD); also elsewhere on the board
unnamed: D1.1 (K), R69.1
unnamed: D2.1 (K), R70.1
unnamed: D3.1 (K), R71.1
unnamed: D4.1 (K), R72.1
unnamed: D5.1 (K), R73.1
unnamed: D6.1 (K), R74.1
unnamed: D7.1 (K), R75.1
unnamed: D8.1 (K), R76.1
unnamed: D9.1 (K), R77.1
unnamed: D10.1 (K), R78.1
unnamed: D11.1 (K), R79.1
unnamed: D12.1 (K), R80.1
unnamed: D13.1 (K), R81.1
unnamed: D14.1 (K), R82.1
unnamed: D15.1 (K), R83.1
unnamed: D16.1 (K), R84.1
unnamed: Q1.3 (D), R69.2
unnamed: Q1.1 (G), U4.15 (QA)
unnamed: Q2.3 (D), R70.2
unnamed: Q2.1 (G), U4.1 (QB)
unnamed: Q3.3 (D), R71.2
unnamed: Q3.1 (G), U4.2 (QC)
unnamed: Q4.3 (D), R72.2
unnamed: Q4.1 (G), U4.3 (QD)
unnamed: Q5.3 (D), R73.2
unnamed: Q5.1 (G), U4.4 (QE)
unnamed: Q6.3 (D), R74.2
unnamed: Q6.1 (G), U4.5 (QF)
unnamed: Q7.3 (D), R75.2
unnamed: Q7.1 (G), U4.6 (QG)
unnamed: Q8.3 (D), R76.2
unnamed: Q8.1 (G), U4.7 (QH)
unnamed: Q9.3 (D), R77.2
unnamed: Q9.1 (G), U5.15 (QA)
unnamed: Q10.3 (D), R78.2
unnamed: Q10.1 (G), U5.1 (QB)
unnamed: Q11.3 (D), R79.2
unnamed: Q11.1 (G), U5.2 (QC)
unnamed: Q12.3 (D), R80.2
unnamed: Q12.1 (G), U5.3 (QD)
unnamed: Q13.3 (D), R81.2
unnamed: Q13.1 (G), U5.4 (QE)
unnamed: Q14.3 (D), R82.2
unnamed: Q14.1 (G), U5.5 (QF)
unnamed: Q15.3 (D), R83.2
unnamed: Q15.1 (G), U5.6 (QG)
unnamed: Q16.3 (D), R84.2
unnamed: Q16.1 (G), U5.7 (QH)
unnamed: U4.9 (QH'), U5.14 (SER)
VCC: C6.1, C7.1, D1.2 (A), D2.2 (A), D3.2 (A), D4.2 (A), D5.2 (A), D6.2 (A), D7.2 (A), D8.2 (A), D9.2 (A), D10.2 (A), D11.2 (A), D12.2 (A), D13.2 (A), D14.2 (A), D15.2 (A), D16.2 (A), U4.10 (~SRCLR), U4.16 (VCC), U5.10 (~SRCLR), U5.16 (VCC); also elsewhere on the board

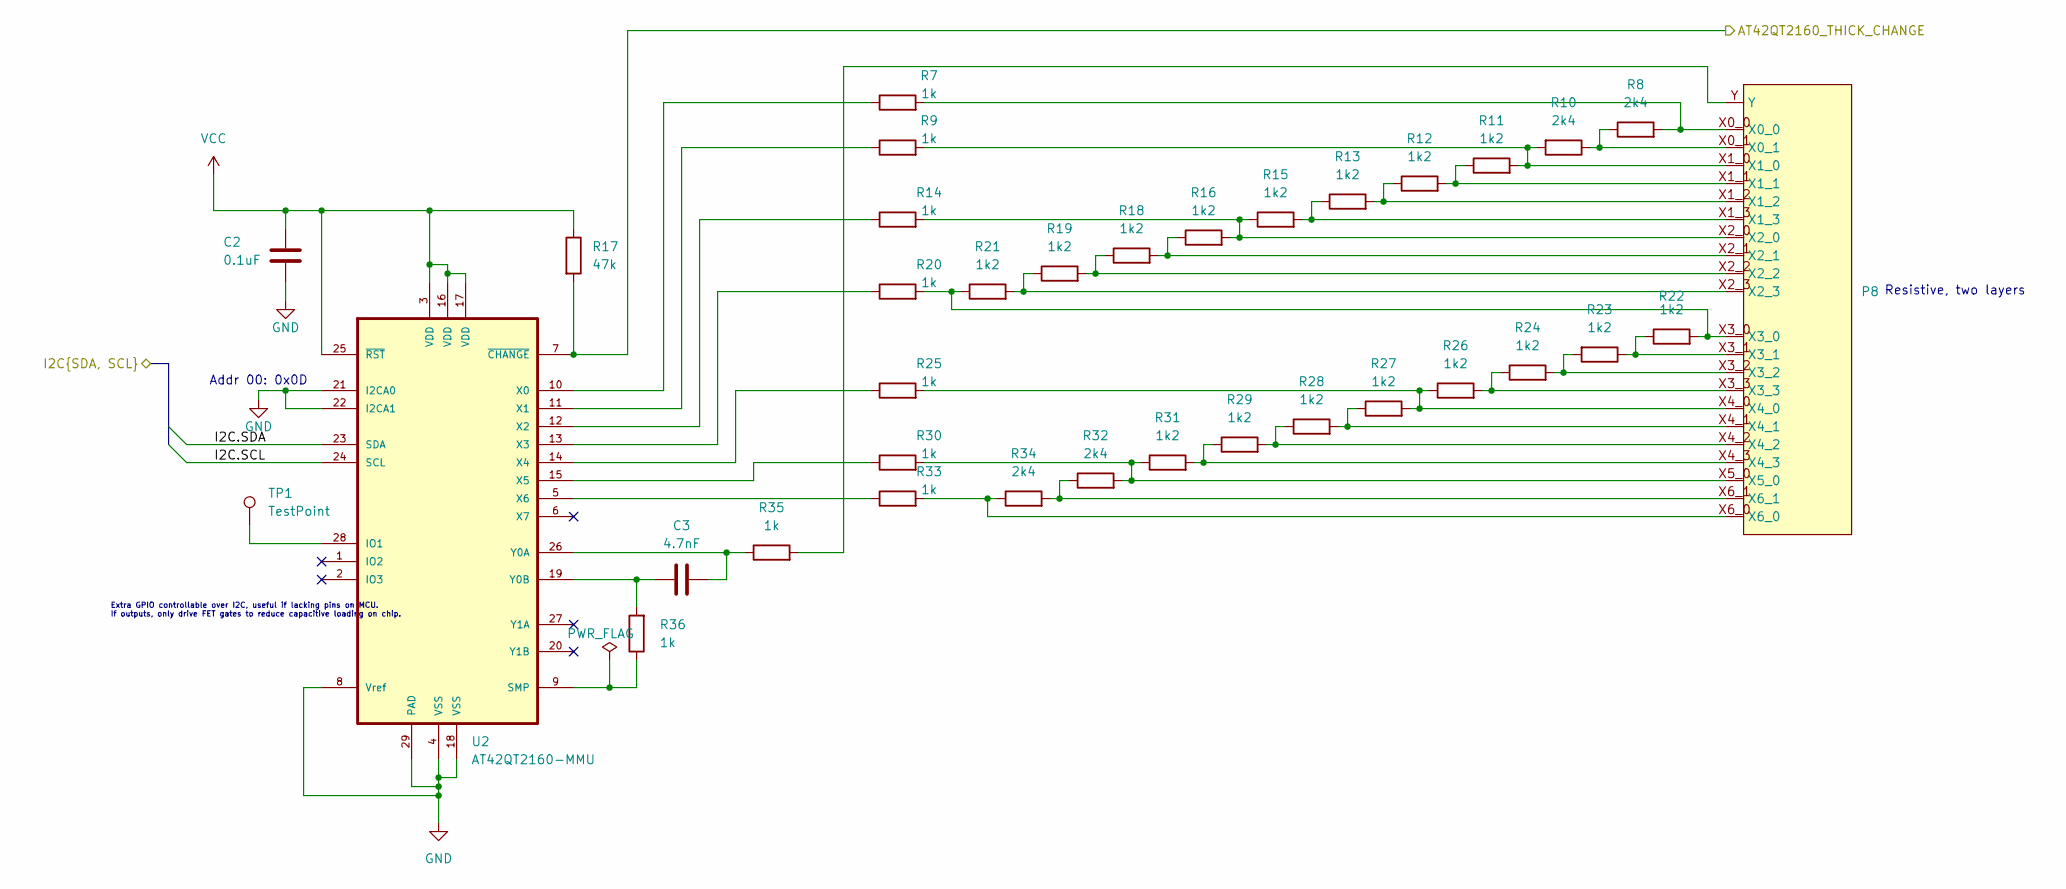
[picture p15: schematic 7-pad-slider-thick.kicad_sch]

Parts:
C2: 0.1uF; C_0603_1608Metric
C3: 4.7nF; C_0603_1608Metric
P8: Slider_ResistiveInterpolation_7P_2L
R7, R9, R14, R20, R25, R30, R33, R35, R36: 1k; R_0603_1608Metric
R8, R10, R32, R34: 2k4; R_0603_1608Metric
R11, R12, R13, R15, R16, R18, R19, R21, R22, R23, R24, R26, R27, R28, R29, R31: 1k2; R_0603_1608Metric
R17: 47k; R_0603_1608Metric
TP1: TestPoint; TestPoint_Pad_D3.0mm
U2: AT42QT2160-MMU; VQFN-28-1EP_4x4mm_P0.45mm_EP2.4x2.4mm_ThermalVias; MPN AT42QT2160-MMU

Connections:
/3-pad-sliders/I2C.SCL: U2.24 (SCL); also elsewhere on the board
/3-pad-sliders/I2C.SDA: U2.23 (SDA); also elsewhere on the board
/7-pad-slider-thick/AT42QT2160_THICK_CHANGE: R17.2, U2.7 (~CHANGE); also elsewhere on the board
GND: C2.2, U2.4 (VSS), U2.8 (Vref), U2.18 (VSS), U2.21 (I2CA0), U2.22 (I2CA1), U2.29 (PAD); also elsewhere on the board
unnamed: P8.X0_0, R7.2, R8.2
unnamed: P8.X0_1, R8.1, R10.1
unnamed: P8.X1_0, R9.2, R10.2, R11.2
unnamed: P8.X1_1, R11.1, R12.2
unnamed: P8.X1_2, R12.1, R13.2
unnamed: P8.X1_3, R13.1, R15.2
unnamed: P8.X2_0, R14.2, R15.1, R16.2
unnamed: P8.X2_1, R16.1, R18.2
unnamed: P8.X2_2, R18.1, R19.2
unnamed: P8.X2_3, R19.1, R21.2
unnamed: P8.X3_0, R20.2, R21.1, R22.2
unnamed: P8.X3_1, R22.1, R23.1
unnamed: P8.X3_2, R23.2, R24.2
unnamed: P8.X3_3, R24.1, R26.2
unnamed: P8.X4_0, R25.2, R26.1, R27.2
unnamed: P8.X4_1, R27.1, R28.2
unnamed: P8.X4_2, R28.1, R29.2
unnamed: P8.X4_3, R29.1, R31.2
unnamed: P8.X5_0, R30.2, R31.1, R32.2
unnamed: P8.X6_0, R33.2, R34.1
unnamed: P8.X6_1, R32.1, R34.2
unnamed: P8.Y, R35.2
unnamed: TP1.1, U2.28 (IO1)
unnamed: R36.1, U2.9 (SMP)
unnamed: R7.1, U2.10 (X0)
unnamed: R9.1, U2.11 (X1)
unnamed: R14.1, U2.12 (X2)
unnamed: R20.1, U2.13 (X3)
unnamed: R25.1, U2.14 (X4)
unnamed: R30.1, U2.15 (X5)
unnamed: R33.1, U2.5 (X6)
unnamed: C3.2, R35.1, U2.26 (Y0A)
unnamed: C3.1, R36.2, U2.19 (Y0B)
VCC: C2.1, R17.1, U2.3 (VDD), U2.16 (VDD), U2.17 (VDD), U2.25 (~RST); also elsewhere on the board

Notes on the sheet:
Addr 00: 0x0D
Extra GPIO controllable over I2C, useful if lacking pins on MCU. If outputs, only drive FET gates to reduce capacitive loading on chip.
Resistive, two layers

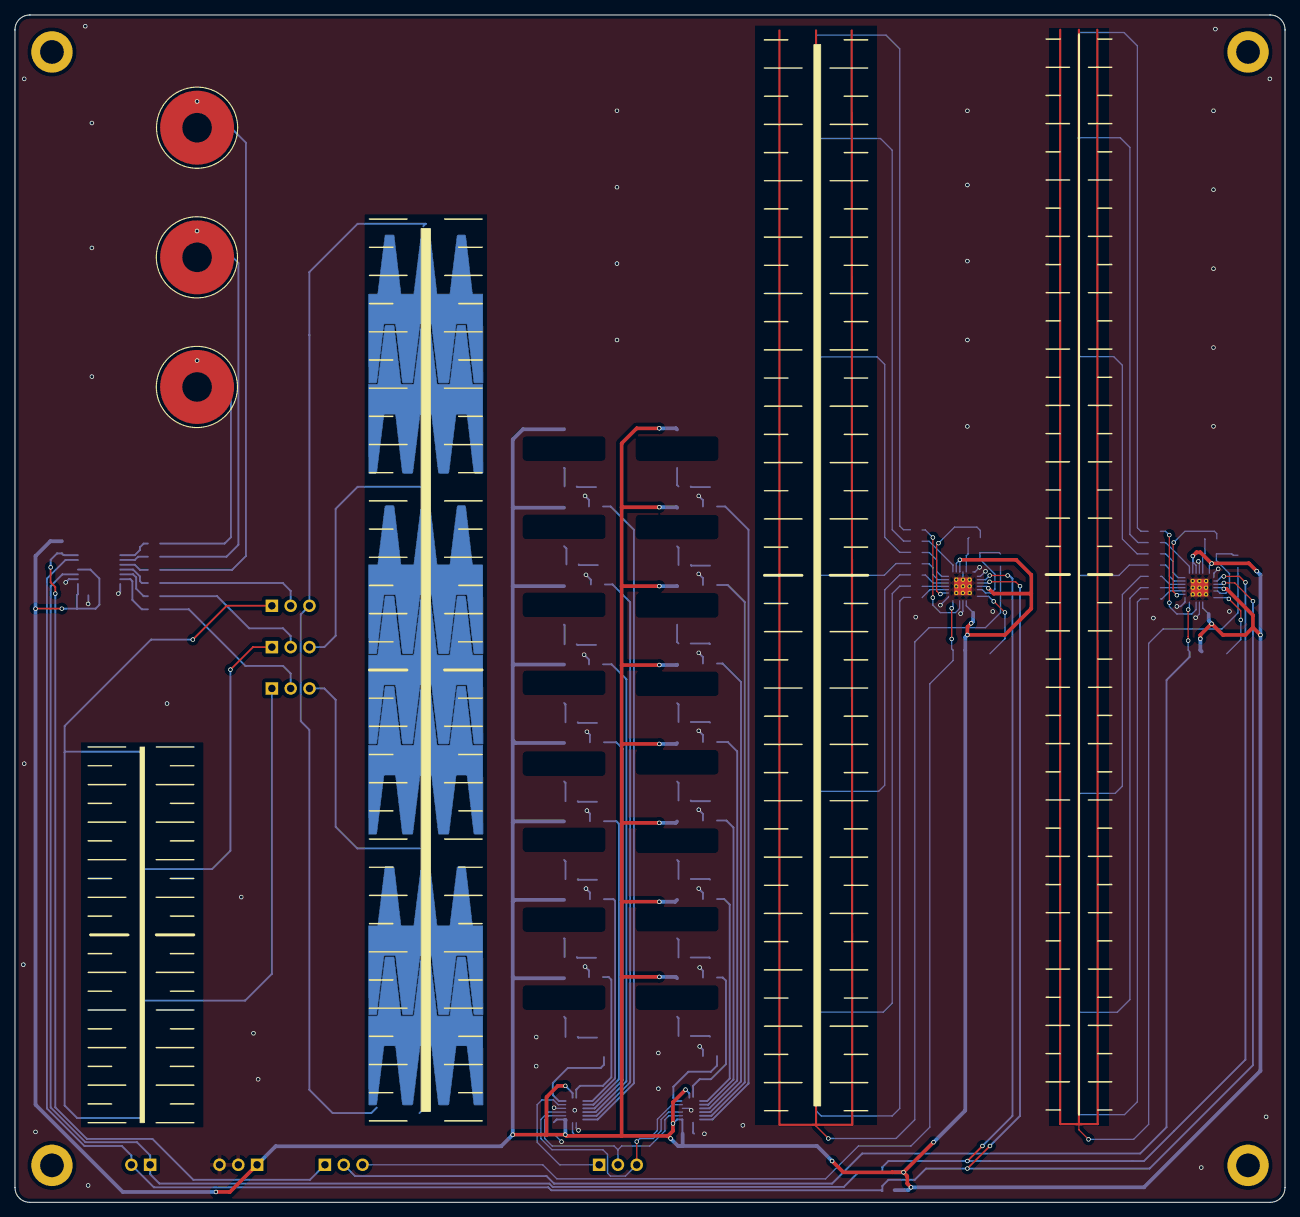
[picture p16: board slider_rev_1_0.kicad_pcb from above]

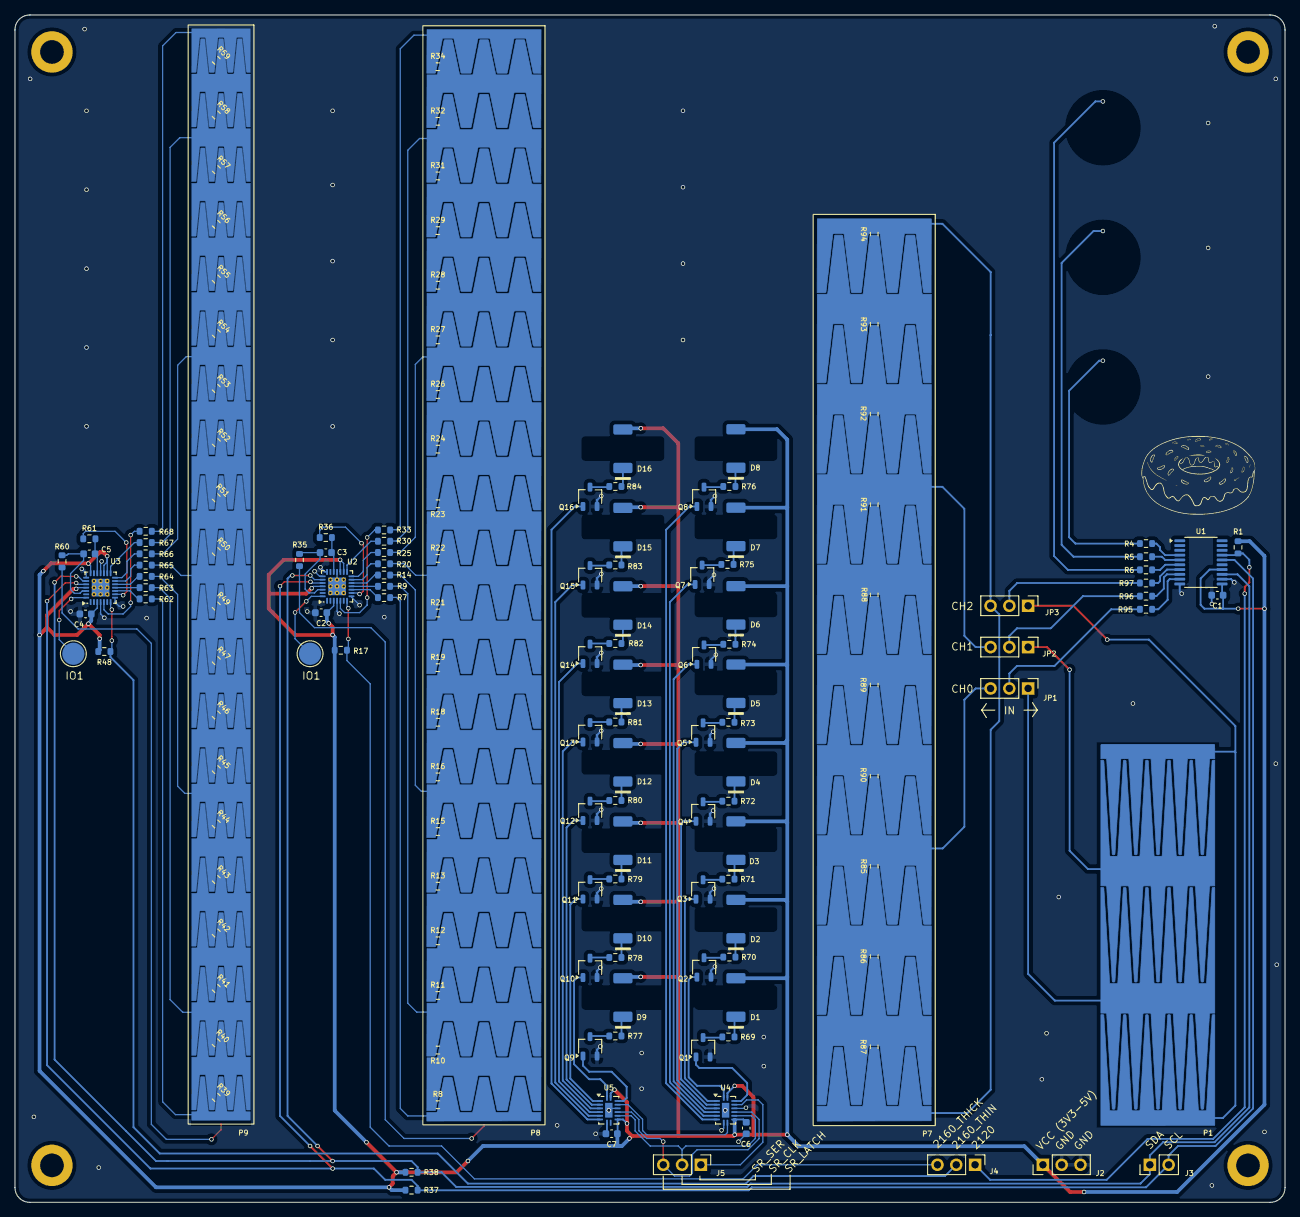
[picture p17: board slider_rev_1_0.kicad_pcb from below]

Board: 2 copper layers, 171.7 x 160.5 mm, 159 parts (152 on the bottom side), 150 nets.

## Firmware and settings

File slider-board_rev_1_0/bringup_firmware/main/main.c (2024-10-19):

#include <string.h>

#include "freertos/FreeRTOS.h"
#include "freertos/task.h"

#include "driver/gpio.h"
#include "driver/i2c.h"
#include "esp_app_trace.h"
#include "esp_log.h"
#include "nvs_flash.h"

#define LED_SR_DATA (GPIO_NUM_25)
#define LED_SR_CLOCK (GPIO_NUM_26)
#define LED_SR_LATCH (GPIO_NUM_27)
#define LED_SR_ALL_ON (0x0001FFFF)
#define LED_SR_OFFSETS (0x0000AAAA)
#define LED_SR_ALL_OFF (0x00000000)

#define I2C_SCL_1 (GPIO_NUM_21)
#define I2C_SDA_1 (GPIO_NUM_2)
#define I2C_EXPECT_ACK (true)
#define AT42QT2120_I2C_ADDR (0x1C)
#define AT42QT2160_THICK_I2C_ADDR (0x0D)
#define AT42QT2160_THIN_I2C_ADDR (0x17)

#define CAP_TOUCH_CHANGE_0 (GPIO_NUM_17)  // 2120
#define CAP_TOUCH_CHANGE_1 (GPIO_NUM_18)  // 2160 thin
#define CAP_TOUCH_CHANGE_2 (GPIO_NUM_19)  // 2160 thick

/*
#define DMX_TX_PIN (GPIO_NUM_21)
#define DMX_RX_PIN (GPIO_NUM_17)
#define DMX_DE_nRE_PIN (GPIO_NUM_18)
*/

#define TAG "main"

typedef struct {
    uint8_t slider_pos;
    bool    slider_detected;
    bool    key0_detected;
    bool    key1_detected;
    bool    key2_detected;
} at42qt2120_key_status_t;

static volatile bool    cap_touch_change_flag;
static volatile uint8_t cap_touch_change_mask;

static void IRAM_ATTR cap_touch_change_isr(void *arg) {
    uint32_t pin = (uint32_t)arg;
    if (pin == CAP_TOUCH_CHANGE_0) {
        cap_touch_change_mask |= 1 << 0;
    } else if (pin == CAP_TOUCH_CHANGE_1) {
        cap_touch_change_mask |= 1 << 1;
    } else if (pin == CAP_TOUCH_CHANGE_2) {
        cap_touch_change_mask |= 1 << 2;
    } else {
        configASSERT(0);
    }

    cap_touch_change_flag = true;
}

static uint16_t slider_pos_to_led_mask(uint8_t slider_pos) {
    uint16_t mask = 0;

    // Doesn't care about higher row of LEDs at all
    uint8_t num_leds = (slider_pos / 32) + 1;
    for (uint8_t i = 0; i < num_leds; i++) {
        mask |= (1 << i);
    }

    return mask;
}

static void led_sr_send(uint32_t mask) {
    gpio_set_level(LED_SR_CLOCK, 0);
    for (uint8_t i = 0; i < 16; i++) {
        gpio_set_level(LED_SR_DATA, (1 << (16 - i - 1) & mask));
        vTaskDelay(pdMS_TO_TICKS(1));
        gpio_set_level(LED_SR_CLOCK, 1);
        vTaskDelay(pdMS_TO_TICKS(1));
        gpio_set_level(LED_SR_CLOCK, 0);
        vTaskDelay(pdMS_TO_TICKS(1));
    }

    vTaskDelay(pdMS_TO_TICKS(1));
    gpio_set_level(LED_SR_LATCH, 1);
    vTaskDelay(pdMS_TO_TICKS(1));
    gpio_set_level(LED_SR_LATCH, 0);
}

static uint8_t i2c_read_byte(uint8_t device_addr, uint8_t mem_addr) {
    i2c_cmd_handle_t i2c_cmd_handle = {0};
    uint8_t          byte           = 0x00;

    // Write internal register addr of key status byte 2 with write bit
    // Build command within cmd handle - nothing is transmitted at this point
    i2c_cmd_handle = i2c_cmd_link_create();
    i2c_master_start(i2c_cmd_handle);
    i2c_master_write_byte(i2c_cmd_handle, (device_addr << 1) | I2C_MASTER_WRITE,
                          I2C_EXPECT_ACK);                            // addr+wr
    i2c_master_write_byte(i2c_cmd_handle, mem_addr, I2C_EXPECT_ACK);  // mem_addr in slave
    i2c_master_stop(i2c_cmd_handle);

    // Transmit constructed cmd sequence
    i2c_master_cmd_begin(I2C_NUM_0, i2c_cmd_handle, pdMS_TO_TICKS(10));

    // Tear down constructed cmd handle for that specific cmd
    i2c_cmd_link_delete(i2c_cmd_handle);

    // Read internal register of key status 0 with read bit
    i2c_cmd_handle = i2c_cmd_link_create();
    i2c_master_start(i2c_cmd_handle);
    i2c_master_write_byte(i2c_cmd_handle, (device_addr << 1) | I2C_MASTER_READ, I2C_EXPECT_ACK);  // addr+re
    i2c_master_read_byte(i2c_cmd_handle, &byte, I2C_MASTER_LAST_NACK);
    i2c_master_stop(i2c_cmd_handle);

    i2c_master_cmd_begin(I2C_NUM_0, i2c_cmd_handle, pdMS_TO_TICKS(10));
    i2c_cmd_link_delete(i2c_cmd_handle);

    // ESP_LOGI(TAG, "addr: 0x%02X = 0x%02X", mem_addr, byte);

    return byte;
}

static void i2c_write_byte(uint8_t device_addr, uint8_t mem_addr, uint8_t value) {
    i2c_cmd_handle_t i2c_cmd_handle = {0};

    // Build command within cmd handle - nothing is transmitted at this point
    i2c_cmd_handle = i2c_cmd_link_create();
    i2c_master_start(i2c_cmd_handle);
    i2c_master_write_byte(i2c_cmd_handle, (device_addr << 1) | I2C_MASTER_WRITE,
                          I2C_EXPECT_ACK);                            // addr+wr
    i2c_master_write_byte(i2c_cmd_handle, mem_addr, I2C_EXPECT_ACK);  // mem_addr in slave
    i2c_master_write_byte(i2c_cmd_handle, value, I2C_EXPECT_ACK);
    i2c_master_stop(i2c_cmd_handle);

    // Transmit constructed cmd sequence
    i2c_master_cmd_begin(I2C_NUM_0, i2c_cmd_handle, pdMS_TO_TICKS(10));

    // Tear down constructed cmd handle for that specific cmd
    i2c_cmd_link_delete(i2c_cmd_handle);
}

static void cap_touch_2120_read_status_bytes(at42qt2120_key_status_t *key_status) {
    uint8_t key_status_0  = i2c_read_byte(AT42QT2120_I2C_ADDR, 0x03);
    uint8_t key_status_1  = i2c_read_byte(AT42QT2120_I2C_ADDR, 0x04);
    uint8_t detect_status = i2c_read_byte(AT42QT2120_I2C_ADDR, 0x02);
    uint8_t slider_pos    = i2c_read_byte(AT42QT2120_I2C_ADDR, 0x05);

    (void)key_status_1;

    if (detect_status & (1 << 1)) {
        // Bit 1 SDET set if slider touch detected (also always sets bit 0 TDET, ignore to prioritize slider)
        key_status->slider_detected = true;
        key_status->slider_pos      = slider_pos;
    } else if (detect_status & (1 << 0)) {
        // Bit 0 TDET set if touch on any key detected
        if (key_status_0 & (1 << 3)) {
            key_status->key0_detected = true;
        } else if (key_status_0 & (1 << 4)) {
            key_status->key1_detected = true;
        } else if (key_status_0 & (1 << 5)) {
            key_status->key2_detected = true;
        }
    }

    ESP_LOGI(TAG, "2120      : Detect status: 0x%02X, Slider pos: 0x%02X", detect_status, slider_pos);
}

static uint8_t cap_touch_2160_thin_read_status_bytes() {
    uint8_t key_status_0  = i2c_read_byte(AT42QT2160_THIN_I2C_ADDR, 0x03);
    uint8_t key_status_1  = i2c_read_byte(AT42QT2160_THIN_I2C_ADDR, 0x04);
    uint8_t detect_status = i2c_read_byte(AT42QT2160_THIN_I2C_ADDR, 0x02);
    uint8_t slider_pos    = i2c_read_byte(AT42QT2160_THIN_I2C_ADDR, 0x05);
    uint8_t gpio_input    = i2c_read_byte(AT42QT2160_THIN_I2C_ADDR, 0x06);

    (void)key_status_0;
    (void)key_status_1;
    (void)detect_status;
    (void)gpio_input;
    // ESP_LOGI(TAG,
    //          "2160 thin : Detect status: 0x%02X, Slider pos: 0x%02X, GPIO: 0x%02X",
    //          detect_status,
    //          slider_pos,
    //          gpio_input);
    return slider_pos;
}

static uint8_t cap_touch_2160_thick_read_status_bytes() {
    uint8_t key_status_0  = i2c_read_byte(AT42QT2160_THICK_I2C_ADDR, 0x03);
    uint8_t key_status_1  = i2c_read_byte(AT42QT2160_THICK_I2C_ADDR, 0x04);
    uint8_t detect_status = i2c_read_byte(AT42QT2160_THICK_I2C_ADDR, 0x02);
    uint8_t slider_pos    = i2c_read_byte(AT42QT2160_THICK_I2C_ADDR, 0x05);
    uint8_t gpio_input    = i2c_read_byte(AT42QT2160_THICK_I2C_ADDR, 0x06);

    (void)key_status_0;
    (void)key_status_1;
    (void)detect_status;
    (void)gpio_input;
    // ESP_LOGI(TAG,
    //          "2160 thick: Detect status: 0x%02X, Slider pos: 0x%02X, GPIO: 0x%02X",
    //          detect_status,
    //          slider_pos,
    //          gpio_input);
    return slider_pos;
}

static void system_init(void) {
    esp_err_t ret = nvs_flash_init();

    if (ret == ESP_ERR_NVS_NO_FREE_PAGES || ret == ESP_ERR_NVS_NEW_VERSION_FOUND) {
        ESP_ERROR_CHECK(nvs_flash_erase());
        ret = nvs_flash_init();
    }

    ESP_ERROR_CHECK(ret);
}

static void system_start(void) {
}

static void app_init() {
    cap_touch_change_flag = false;
    cap_touch_change_mask = 0x00;

    gpio_config_t output_config = {
        .pin_bit_mask = (1ULL << LED_SR_DATA) | (1ULL << LED_SR_CLOCK) | (1ULL << LED_SR_LATCH),
        .intr_type    = GPIO_INTR_DISABLE,
        .mode         = GPIO_MODE_OUTPUT,
        .pull_up_en   = false,
        .pull_down_en = false,
    };
    ESP_ERROR_CHECK(gpio_config(&output_config));

    gpio_config_t input_interrupt_config = {
        .pin_bit_mask = (1ULL << CAP_TOUCH_CHANGE_0) | (1ULL << CAP_TOUCH_CHANGE_1) | (1ULL << CAP_TOUCH_CHANGE_2),
        .intr_type    = GPIO_INTR_NEGEDGE,
        .mode         = GPIO_MODE_INPUT,
        .pull_up_en   = false,  // pulled up externally
        .pull_down_en = false,
    };
    ESP_ERROR_CHECK(gpio_config(&input_interrupt_config));
    gpio_install_isr_service(0x0);
    gpio_isr_handler_add(CAP_TOUCH_CHANGE_0, cap_touch_change_isr, (void *)CAP_TOUCH_CHANGE_0);
    gpio_isr_handler_add(CAP_TOUCH_CHANGE_1, cap_touch_change_isr, (void *)CAP_TOUCH_CHANGE_1);
    gpio_isr_handler_add(CAP_TOUCH_CHANGE_2, cap_touch_change_isr, (void *)CAP_TOUCH_CHANGE_2);

    i2c_config_t i2c_config = {
        .mode             = I2C_MODE_MASTER,
        .sda_io_num       = I2C_SDA_1,
        .sda_pullup_en    = GPIO_PULLUP_DISABLE,
        .scl_io_num       = I2C_SCL_1,
        .scl_pullup_en    = GPIO_PULLUP_DISABLE,
        .master.clk_speed = 100000,
        .clk_flags        = 0,
    };

    ESP_ERROR_CHECK(i2c_param_config(I2C_NUM_0, &i2c_config));
    ESP_ERROR_CHECK(i2c_driver_install(I2C_NUM_0, I2C_MODE_MASTER, 0, 0, 0));
}

static void app_start(void) {
}

void app_main(void) {
    ESP_LOGI(TAG, "Starting cap-touch-slider-board firmware");

    esp_log_level_set(TAG, ESP_LOG_DEBUG);

    system_init();
    system_start();

    app_init();
    app_start();

    // Enable slider for 2120
    ESP_LOGI(TAG, "********* SETTING UP 2120 *********");
    uint8_t slider_options_val = i2c_read_byte(AT42QT2120_I2C_ADDR, 0x0E);
    ESP_LOGI(TAG, "2120 slider options reg PRE: 0x%02X", slider_options_val);
    i2c_write_byte(AT42QT2120_I2C_ADDR, 0x0E, (1 << 7));  // enable slider
    slider_options_val = i2c_read_byte(AT42QT2120_I2C_ADDR, 0x0E);
    ESP_LOGI(TAG, "2120 slider options reg POST: 0x%02X", slider_options_val);

    ESP_LOGI(TAG, "********* SETTING UP 2160 THICK *********");
    // Set resolution for 2160 thick
    slider_options_val = i2c_read_byte(AT42QT2160_THICK_I2C_ADDR, 0x15);
    ESP_LOGI(TAG, "2160 thick slider options reg PRE: 0x%02X", slider_options_val);
    i2c_write_byte(AT42QT2160_THICK_I2C_ADDR, 0x15, 0x00);  // 8 bits resolution
    slider_options_val = i2c_read_byte(AT42QT2160_THICK_I2C_ADDR, 0x15);
    ESP_LOGI(TAG, "2160 thick slider options reg POST: 0x%02X", slider_options_val);

    // Set num keys for 2160 thick (leave hysteresis top nibble alone)
    uint8_t slider_control_val = i2c_read_byte(AT42QT2160_THICK_I2C_ADDR, 0x14);
    ESP_LOGI(TAG, "2160 thick Slider control reg PRE: 0x%02X", slider_control_val);
    i2c_write_byte(AT42QT2160_THICK_I2C_ADDR, 0x14, (slider_control_val | 0x07));
    slider_options_val = i2c_read_byte(AT42QT2160_THICK_I2C_ADDR, 0x14);
    ESP_LOGI(TAG, "2160 thick slider control reg POST: 0x%02X", slider_control_val);

    // Calibrate 2160 thick after setup
    i2c_write_byte(AT42QT2160_THICK_I2C_ADDR, 0x0A, 0xFF);
    ESP_LOGI(TAG, "Kicked calibration for 2160 thick");

    ESP_LOGI(TAG, "********* SETTING UP 2160 THIN *********");
    slider_options_val = i2c_read_byte(AT42QT2160_THIN_I2C_ADDR, 0x15);
    ESP_LOGI(TAG, "2160 thin slider options reg PRE: 0x%02X", slider_options_val);
    i2c_write_byte(AT42QT2160_THIN_I2C_ADDR, 0x15, 0x00);  // 8 bits resolution
    slider_options_val = i2c_read_byte(AT42QT2160_THIN_I2C_ADDR, 0x15);
    ESP_LOGI(TAG, "2160 thin slider options reg POST: 0x%02X", slider_options_val);

    // Set num keys for 2160 thin (leave hysteresis top nibble alone)
    slider_control_val = i2c_read_byte(AT42QT2160_THIN_I2C_ADDR, 0x14);
    ESP_LOGI(TAG, "2160 thin Slider control reg PRE: 0x%02X", slider_control_val);
    i2c_write_byte(AT42QT2160_THIN_I2C_ADDR, 0x14, (slider_control_val | 0x07));
    slider_options_val = i2c_read_byte(AT42QT2160_THIN_I2C_ADDR, 0x14);
    ESP_LOGI(TAG, "2160 thin slider control reg POST: 0x%02X", slider_control_val);

    // Calibrate 2160 thin after setup
    i2c_write_byte(AT42QT2160_THIN_I2C_ADDR, 0x0A, 0xFF);
    ESP_LOGI(TAG, "Kicked calibration for 2160 thin");

    vTaskDelay(pdMS_TO_TICKS(10));

    at42qt2120_key_status_t key_status = {0};
    (void)cap_touch_2120_read_status_bytes(&key_status);
    (void)cap_touch_2160_thick_read_status_bytes();
    (void)cap_touch_2160_thin_read_status_bytes();
    memset(&key_status, 0x00, sizeof(at42qt2120_key_status_t));

    // TODO :: set gpios all outputs for 2160, otherwise the gpio1 TP triggers capacitively

    uint16_t led_mask = LED_SR_OFFSETS;
    led_sr_send(led_mask);
    ESP_LOGI(TAG, "Sent SR bytes");

    uint8_t slider_pos = 0;
    while (1) {
        if (cap_touch_change_flag) {
            cap_touch_change_flag = false;
            // ESP_LOGW(TAG, "cap touch change flag! mask: %u", cap_touch_change_mask);

            if (cap_touch_change_mask & (1 << 0)) {
                cap_touch_2120_read_status_bytes(&key_status);
                if (key_status.slider_detected) {
                    slider_pos = key_status.slider_pos;
                } else if (key_status.key0_detected || key_status.key1_detected || key_status.key2_detected) {
                    led_sr_send(LED_SR_ALL_OFF);
                }

                memset(&key_status, 0x00, sizeof(at42qt2120_key_status_t));
            }

            if (cap_touch_change_mask & (1 << 1)) {
                slider_pos = cap_touch_2160_thin_read_status_bytes();
            }

            if (cap_touch_change_mask & (1 << 2)) {
                slider_pos = cap_touch_2160_thick_read_status_bytes();
            }

            if (slider_pos != 0) {
                led_mask = slider_pos_to_led_mask(slider_pos);

                // ESP_LOGI(TAG, "Sending slider pos: %u, mask: 0x%02X", slider_pos, led_mask);
                led_sr_send(led_mask);
                slider_pos = 0;
            }

            cap_touch_change_mask = 0;
        }

        vTaskDelay(pdMS_TO_TICKS(1));
    }
}
